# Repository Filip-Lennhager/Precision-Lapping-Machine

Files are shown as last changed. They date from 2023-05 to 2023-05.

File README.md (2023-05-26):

# Precision Lapping Machine

This project was created by:

+ Filip Lennhager, `filip@lennhager.se`
+ Filip Karlsson
+ Albin Magnusson
+ Ali Halbastian Abdulla
+ Anton Meuller
+ Christian Mallqui Castro
+ Toni Carillo

## Table of Contents

1. [Prototype](#prototype)
2. [Disc and Fixation](#disc-and-fixation)
3. [Gearbox](#gearbox)
4. [Control System](#control-system)
    + [PCB](#pcb)
        + [Electrical Schematic](#electrical-schematic)
        + [Physical Schematic](#electrical-schematic)
    + [Code](#code)

## Prototype

CAD model of the prototype:

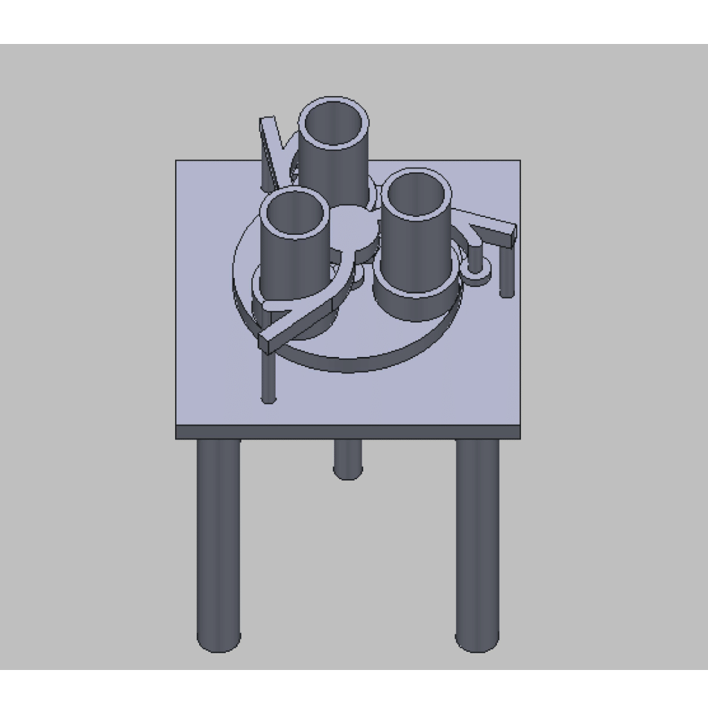
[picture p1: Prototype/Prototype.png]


## Disc and Fixation

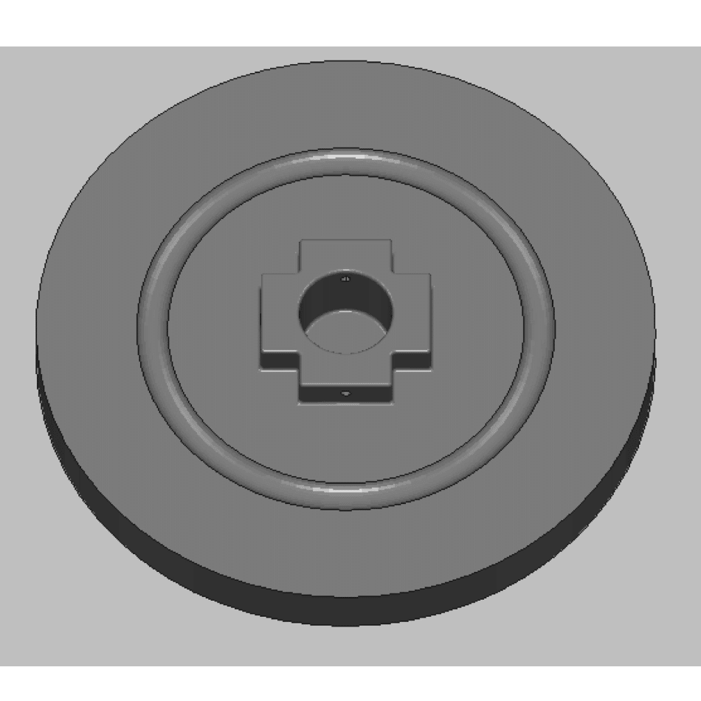
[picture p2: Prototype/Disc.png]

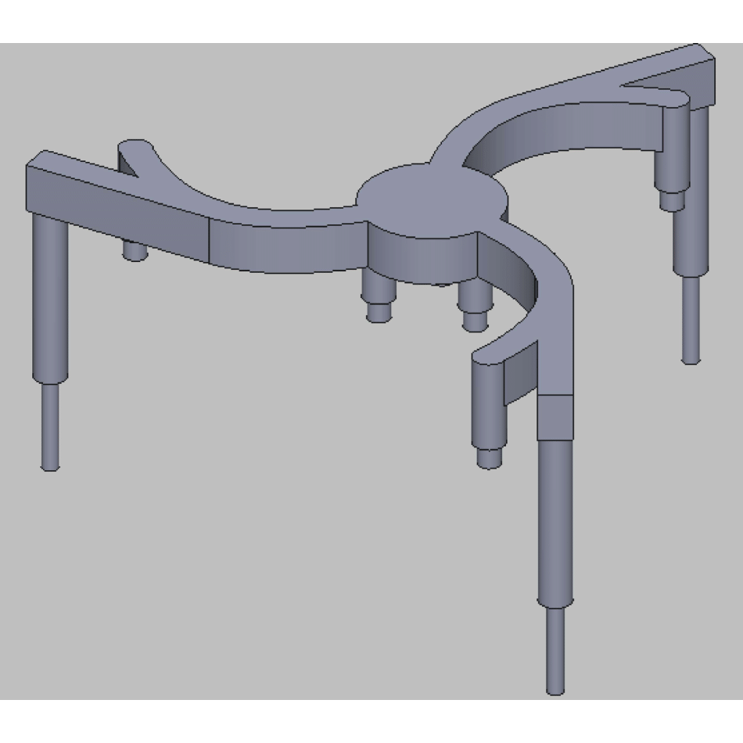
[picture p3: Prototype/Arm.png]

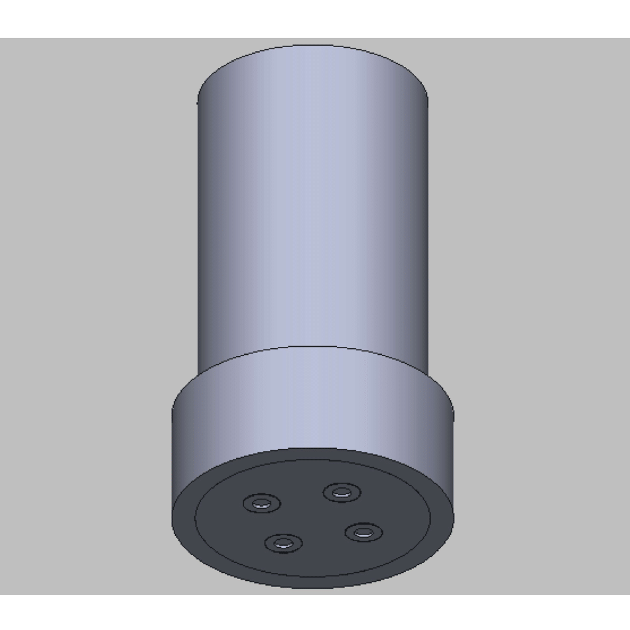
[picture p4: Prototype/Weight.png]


## Gearbox

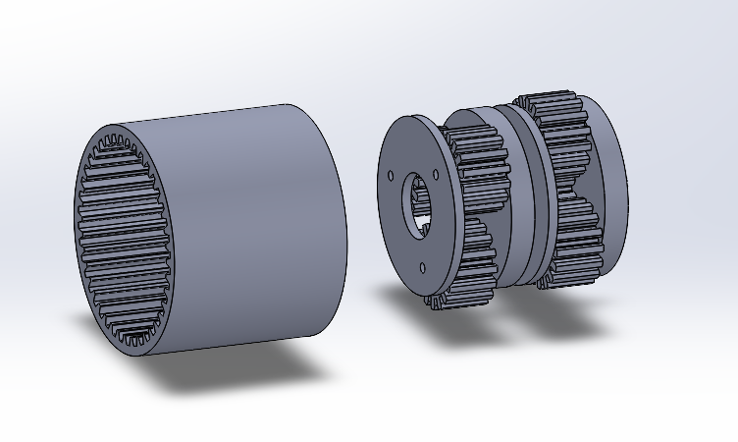
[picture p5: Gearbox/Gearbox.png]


## Control System

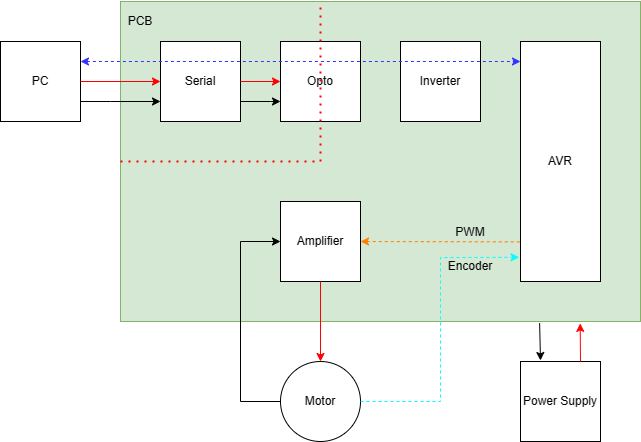
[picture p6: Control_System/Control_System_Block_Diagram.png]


### PCB

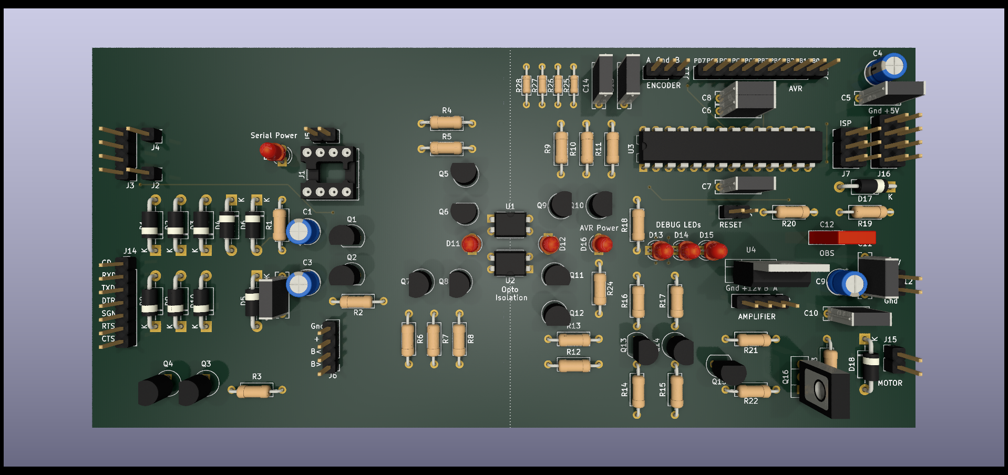
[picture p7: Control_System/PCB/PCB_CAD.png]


#### Electrical Schematic

An overview of the electrical schematic can be found in the file: [`Precision-Lapping-Machine-1.png`](Control_System/PCB/Electrical_Schematic/Precision-Lapping-Machine-1.png):

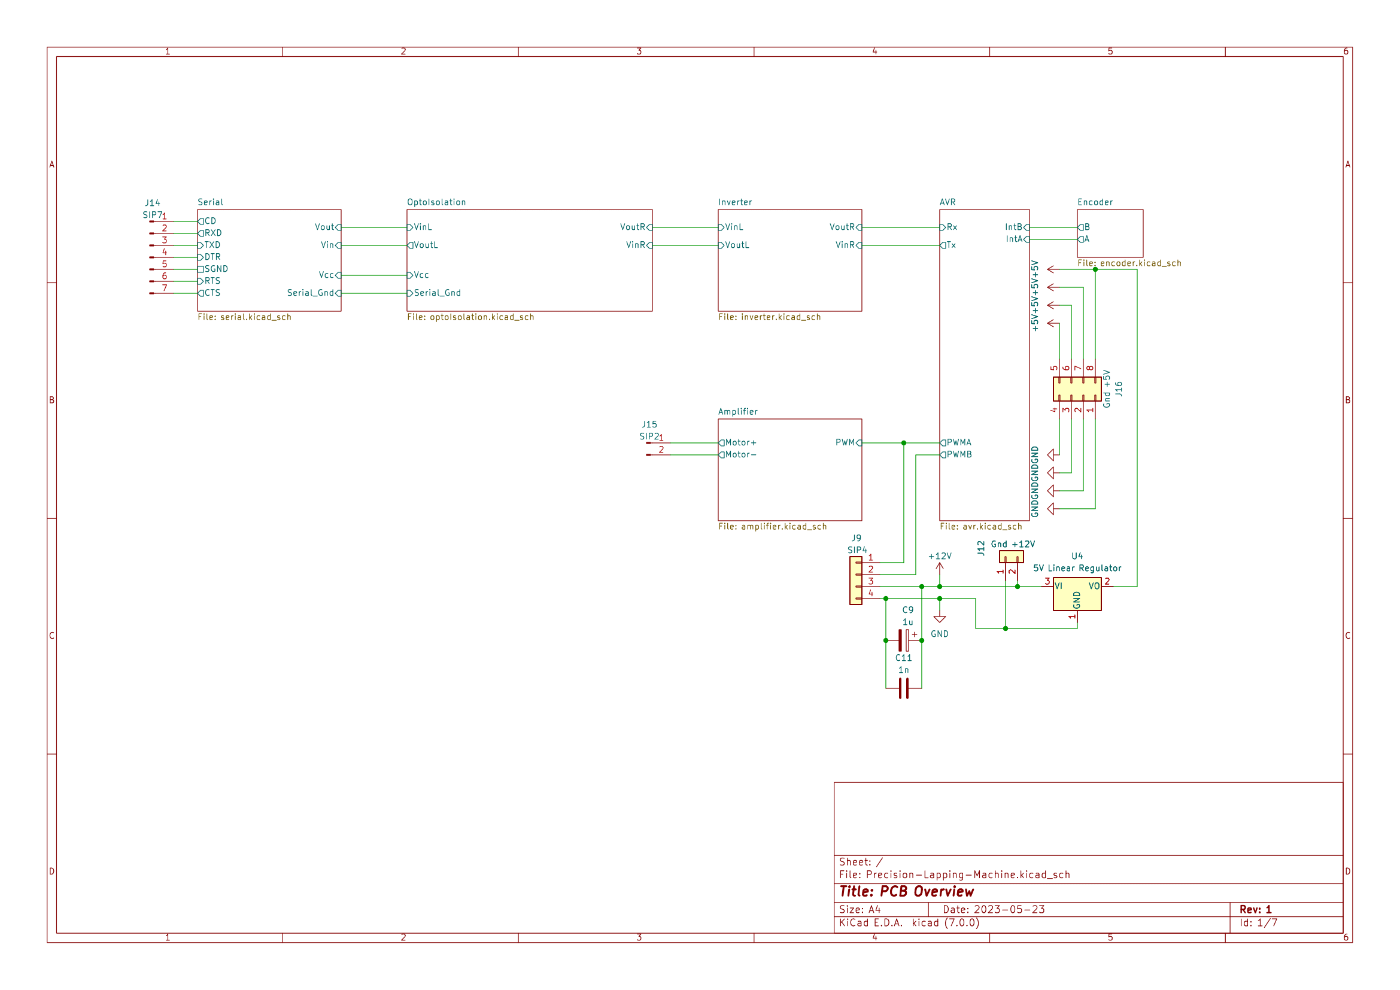
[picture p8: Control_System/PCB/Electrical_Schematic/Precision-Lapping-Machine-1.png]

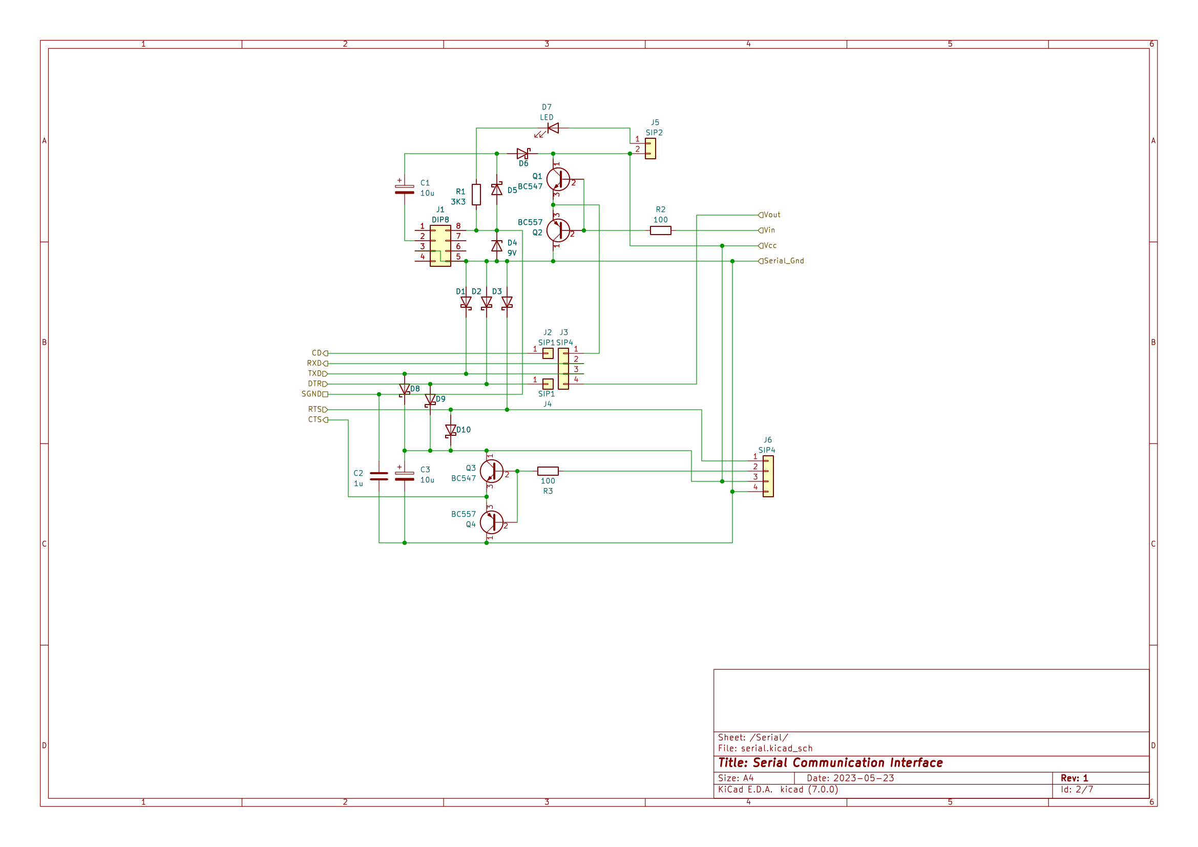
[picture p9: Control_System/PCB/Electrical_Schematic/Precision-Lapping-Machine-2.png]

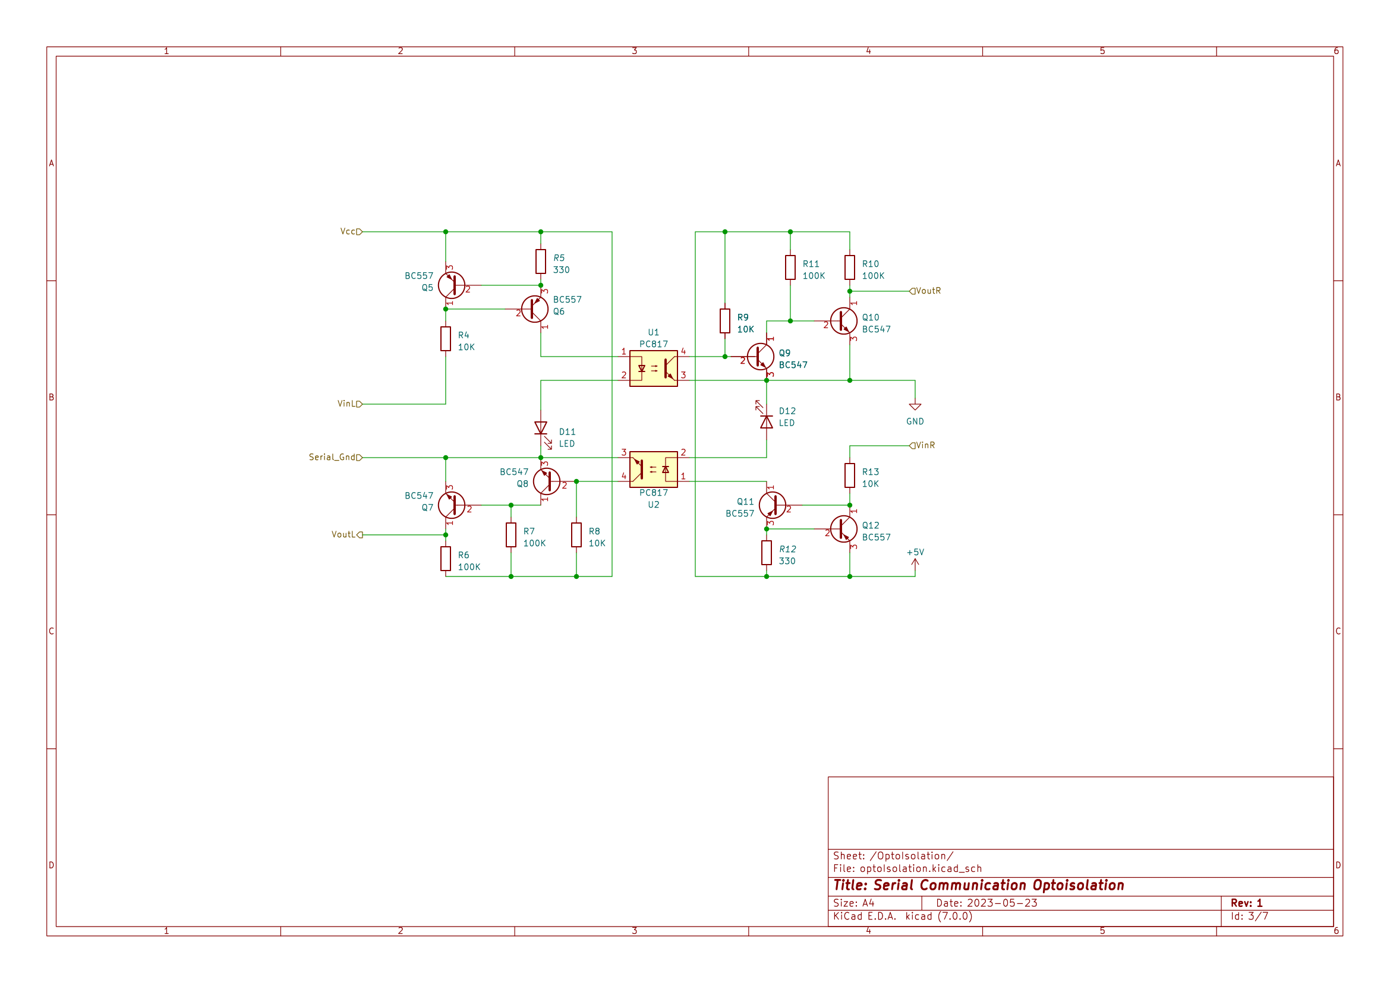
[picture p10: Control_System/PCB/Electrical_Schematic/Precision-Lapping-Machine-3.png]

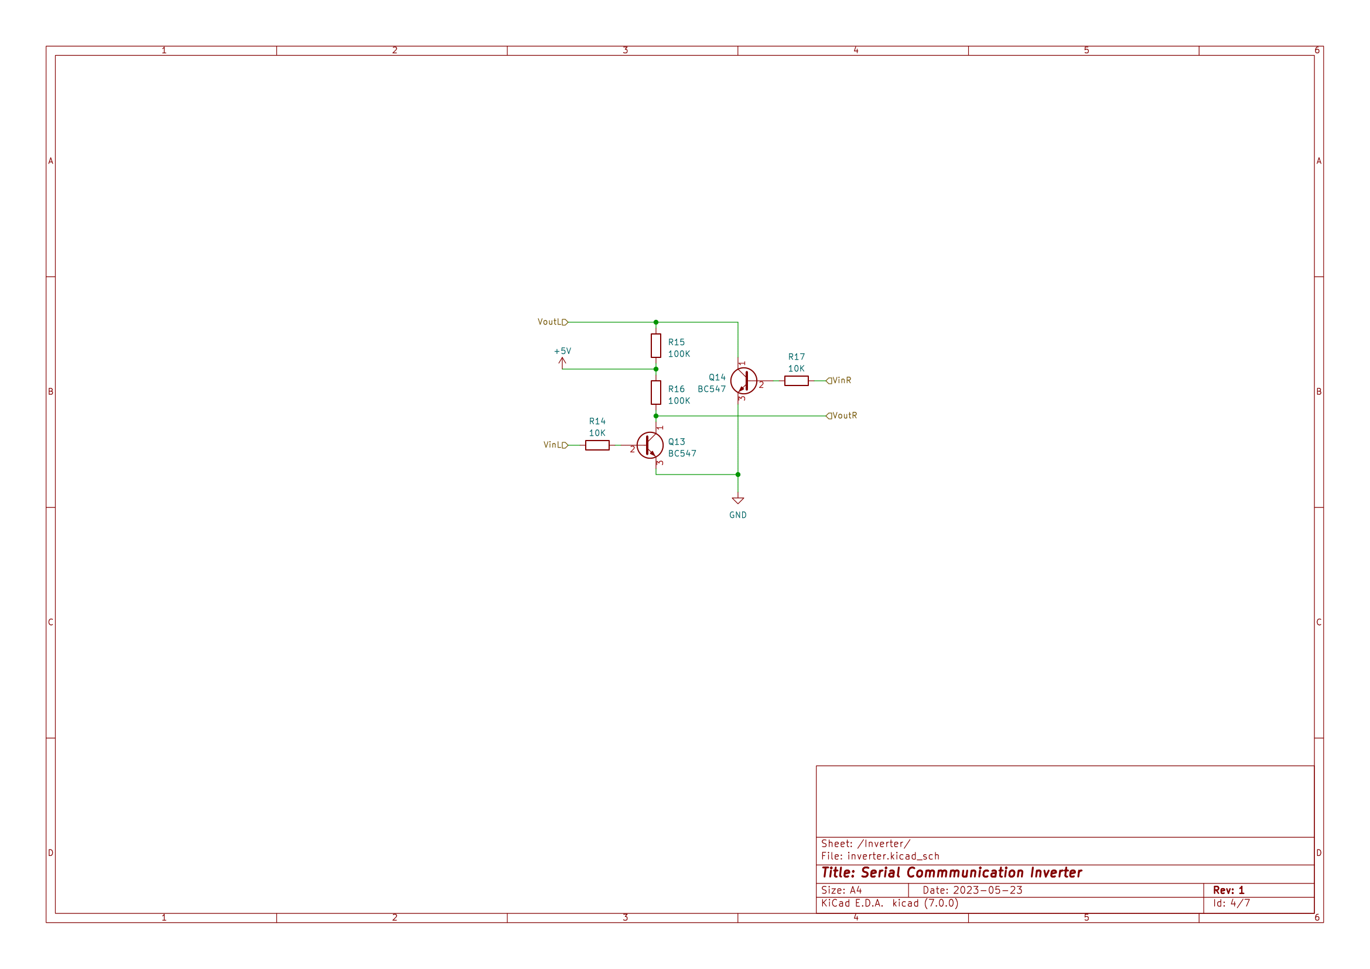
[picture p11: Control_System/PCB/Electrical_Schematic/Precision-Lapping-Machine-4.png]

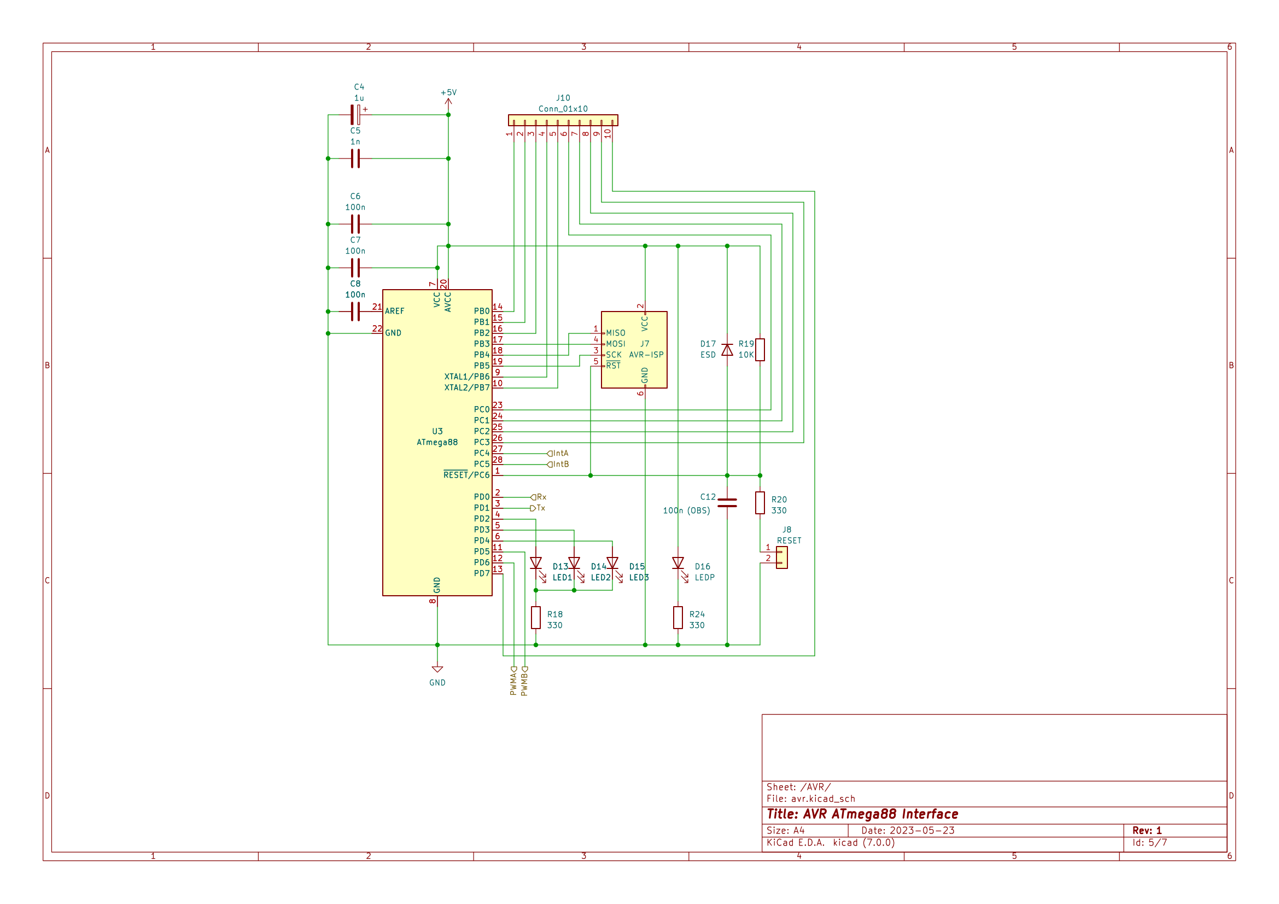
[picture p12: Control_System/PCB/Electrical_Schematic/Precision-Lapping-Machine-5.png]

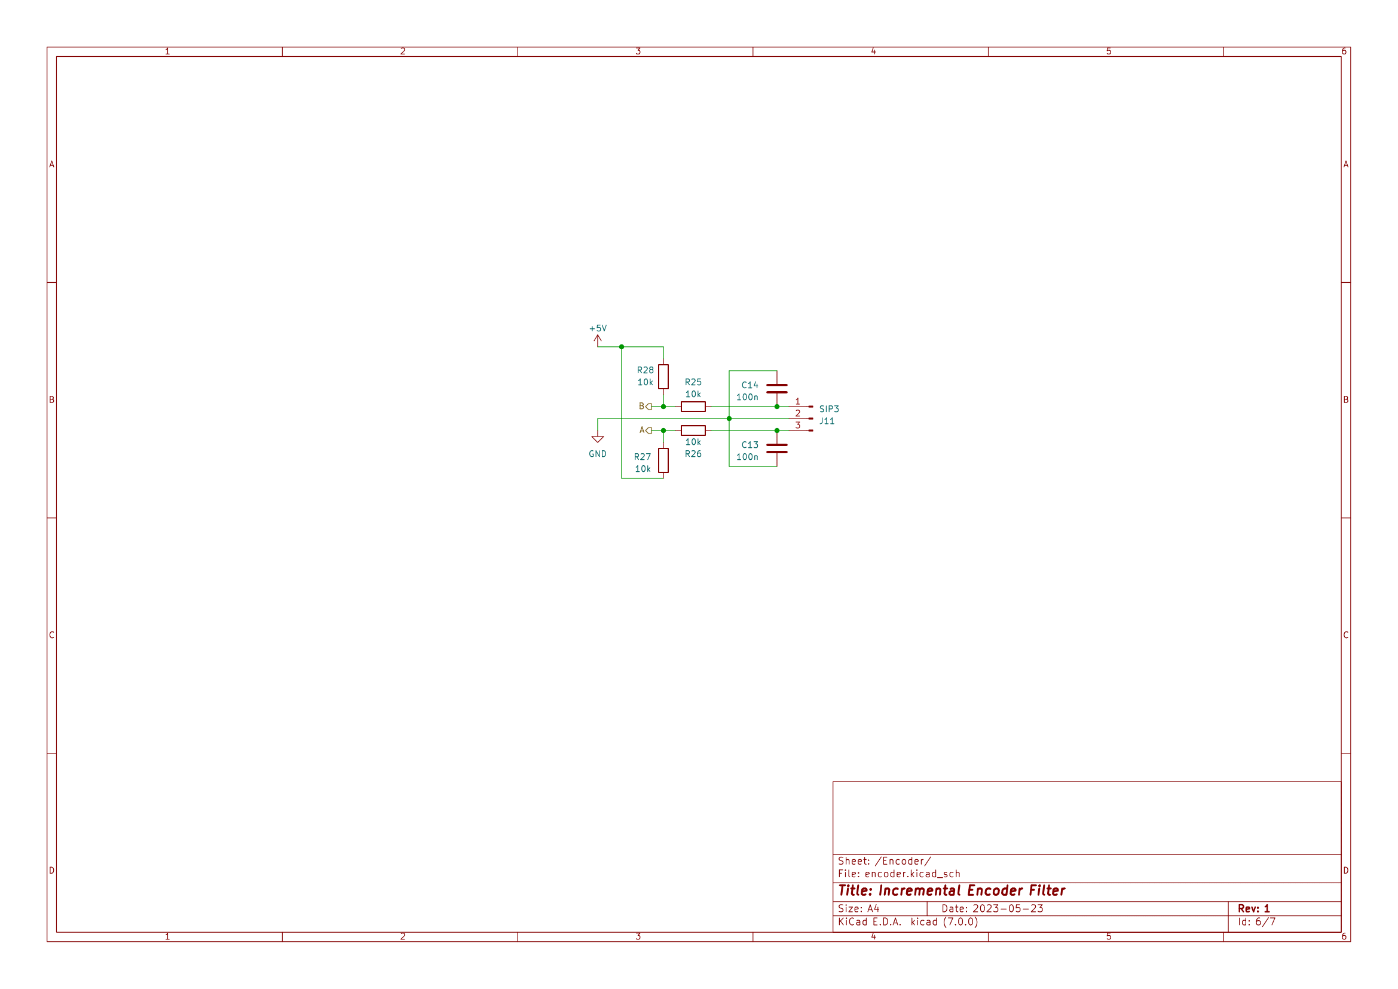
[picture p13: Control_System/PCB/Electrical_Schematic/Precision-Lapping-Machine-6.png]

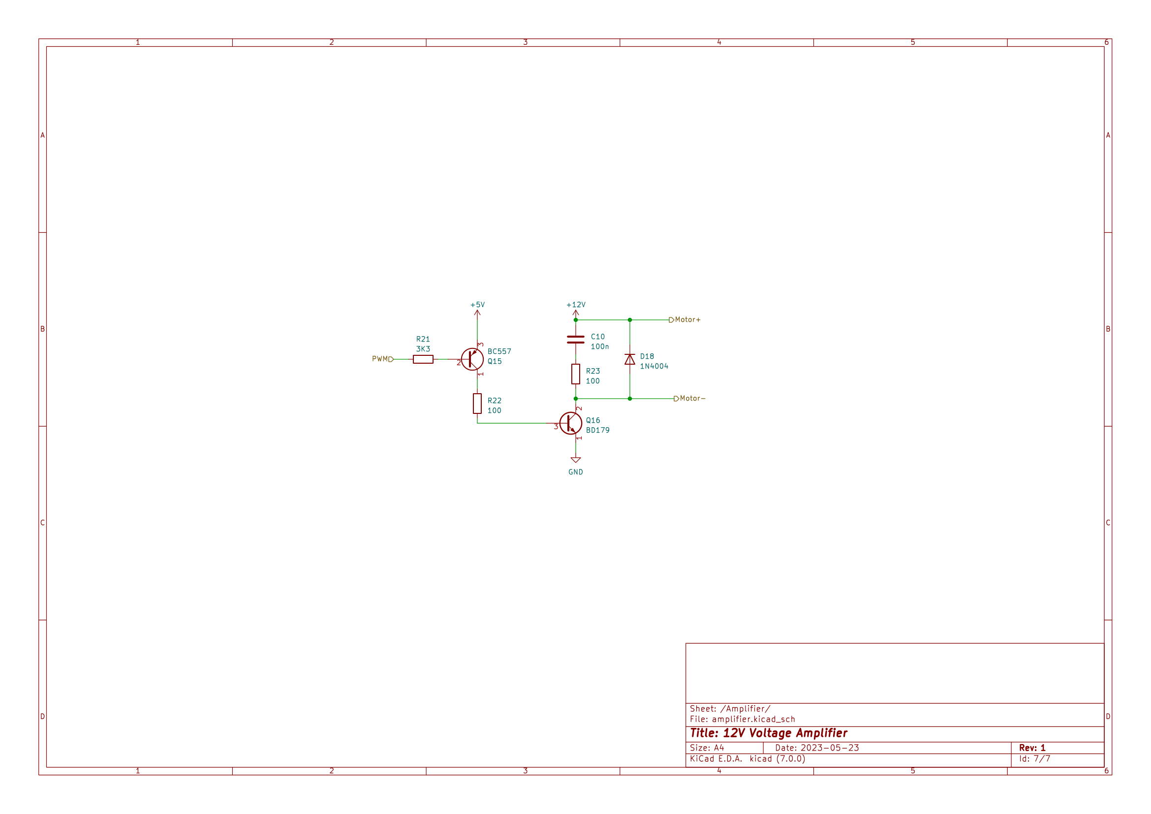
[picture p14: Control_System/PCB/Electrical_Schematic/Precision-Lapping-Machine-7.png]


#### Physical Schematic

Schematic of PCB with physical component placement:

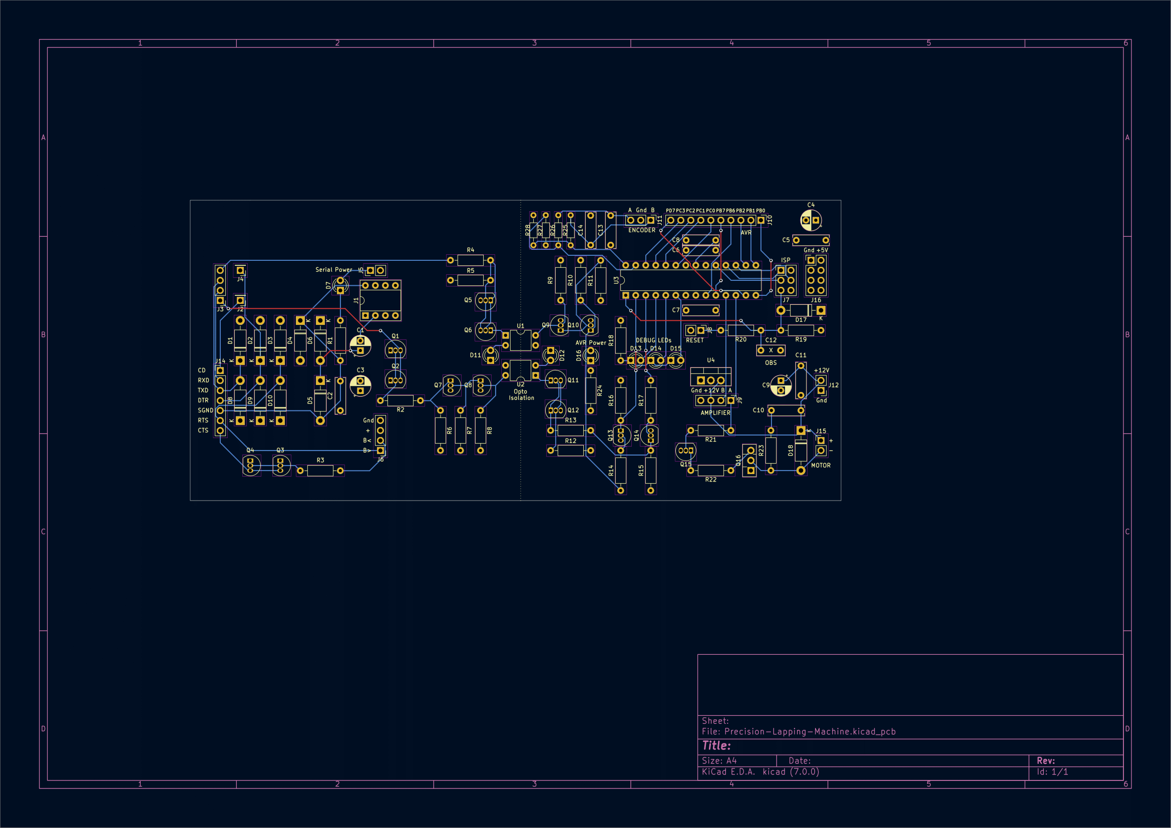
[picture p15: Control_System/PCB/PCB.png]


Gerber and drill files for pcb fabrication:

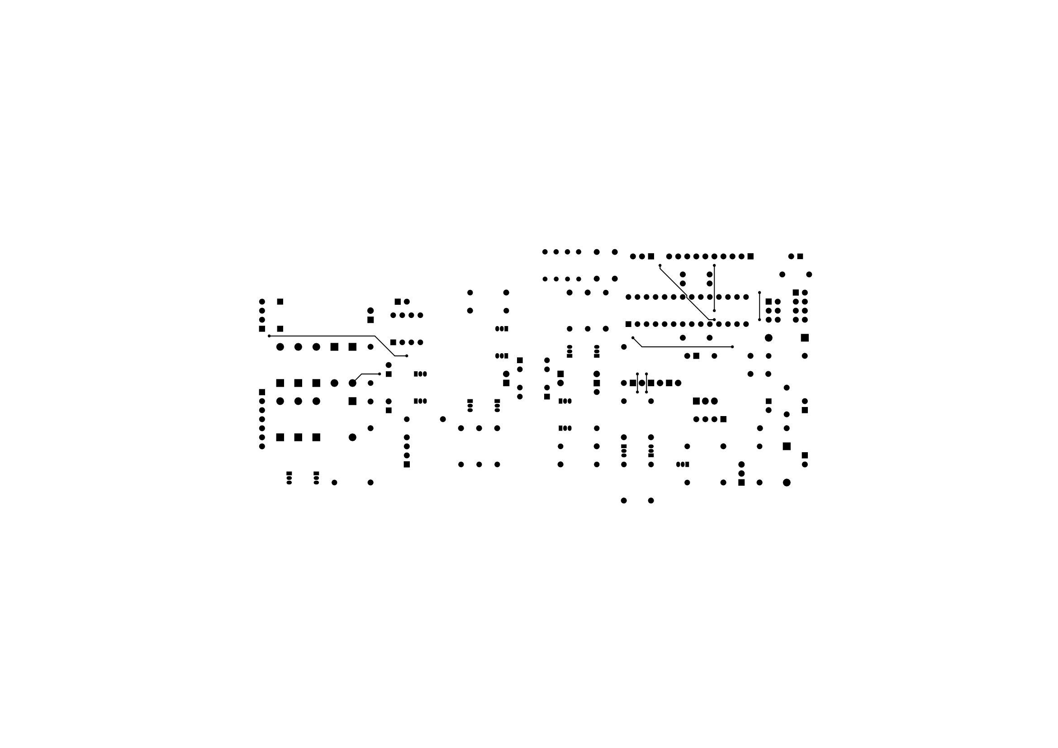
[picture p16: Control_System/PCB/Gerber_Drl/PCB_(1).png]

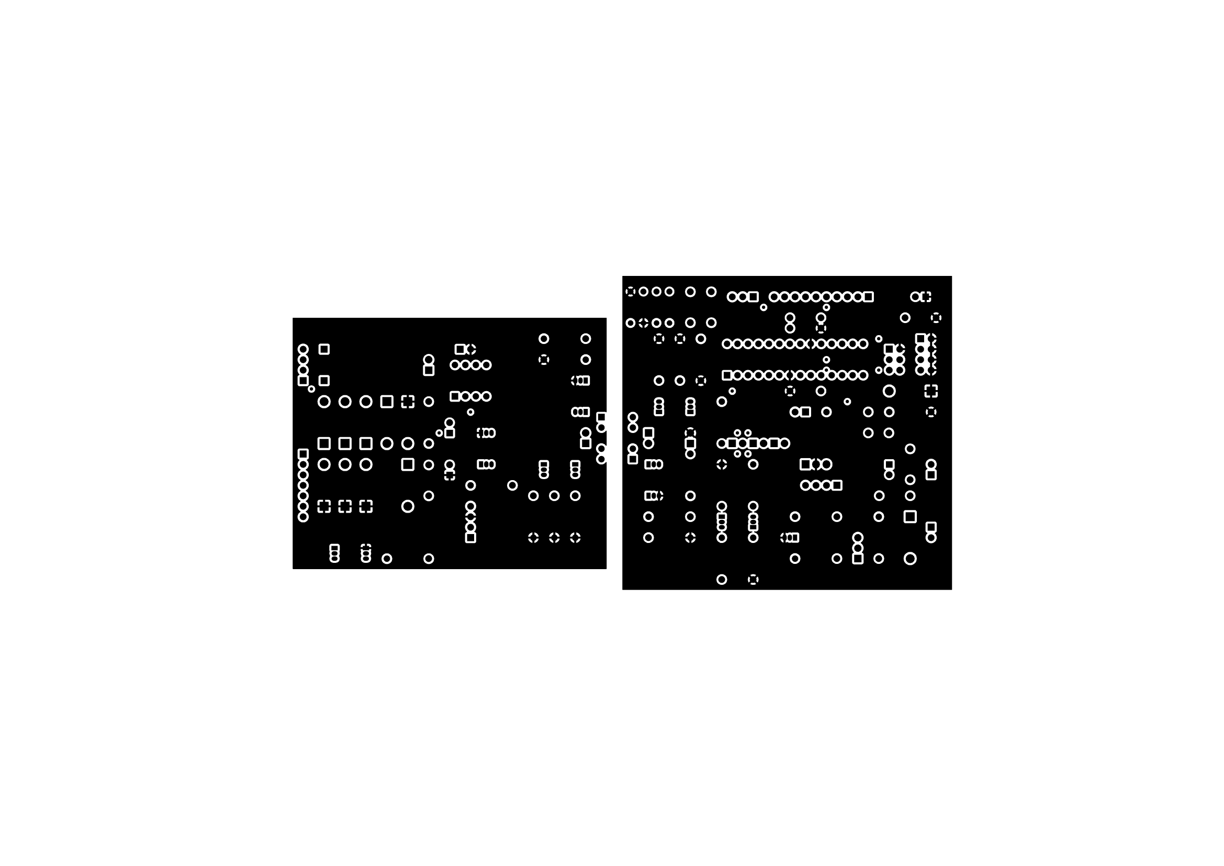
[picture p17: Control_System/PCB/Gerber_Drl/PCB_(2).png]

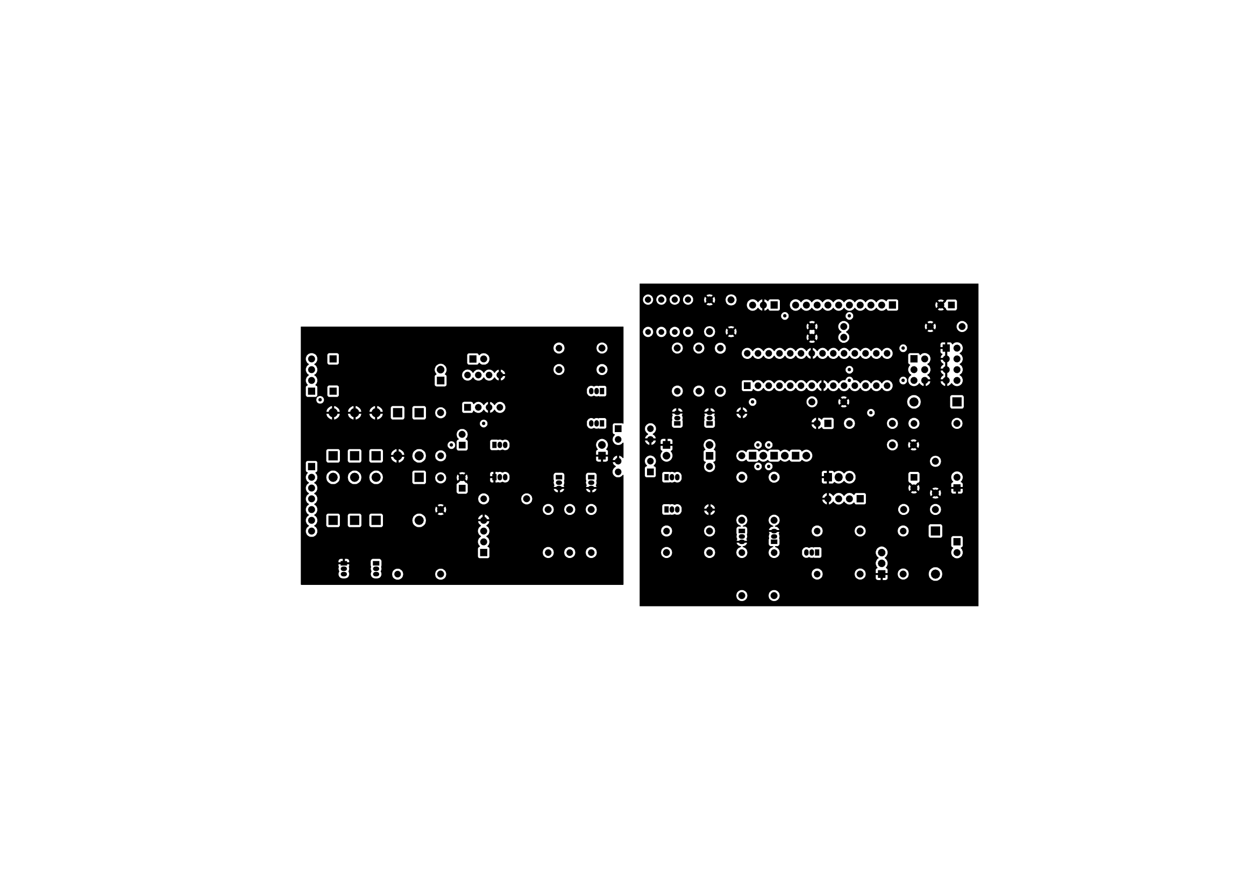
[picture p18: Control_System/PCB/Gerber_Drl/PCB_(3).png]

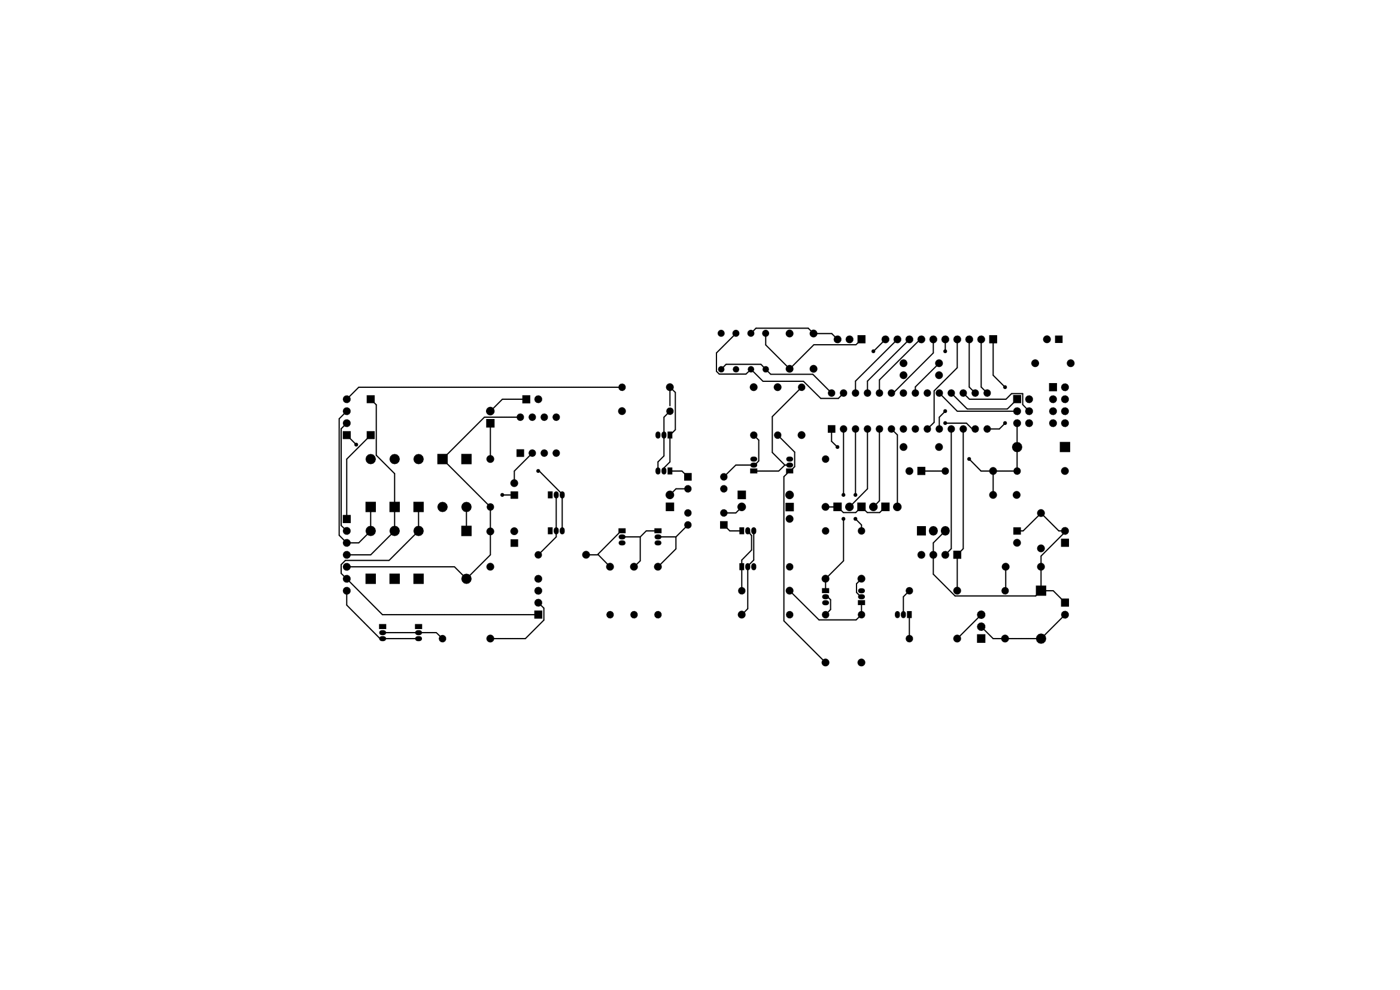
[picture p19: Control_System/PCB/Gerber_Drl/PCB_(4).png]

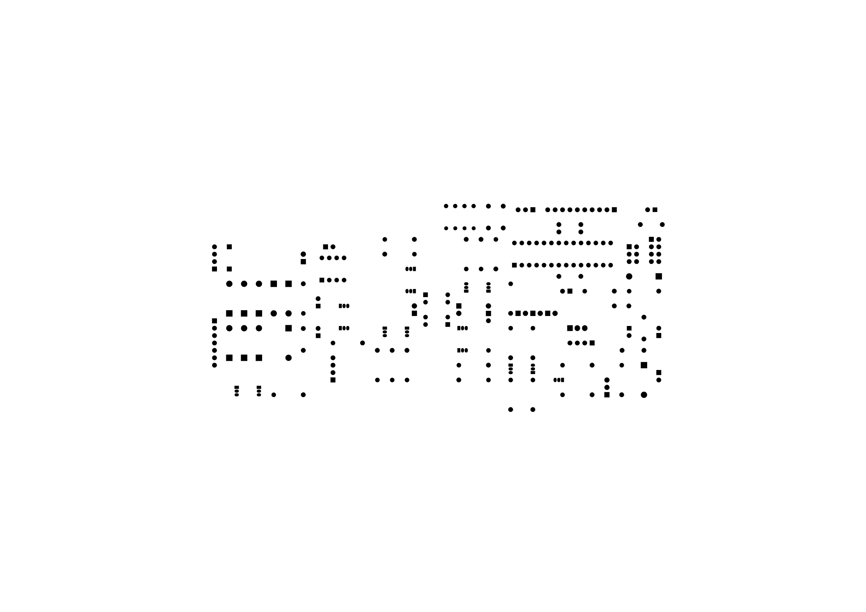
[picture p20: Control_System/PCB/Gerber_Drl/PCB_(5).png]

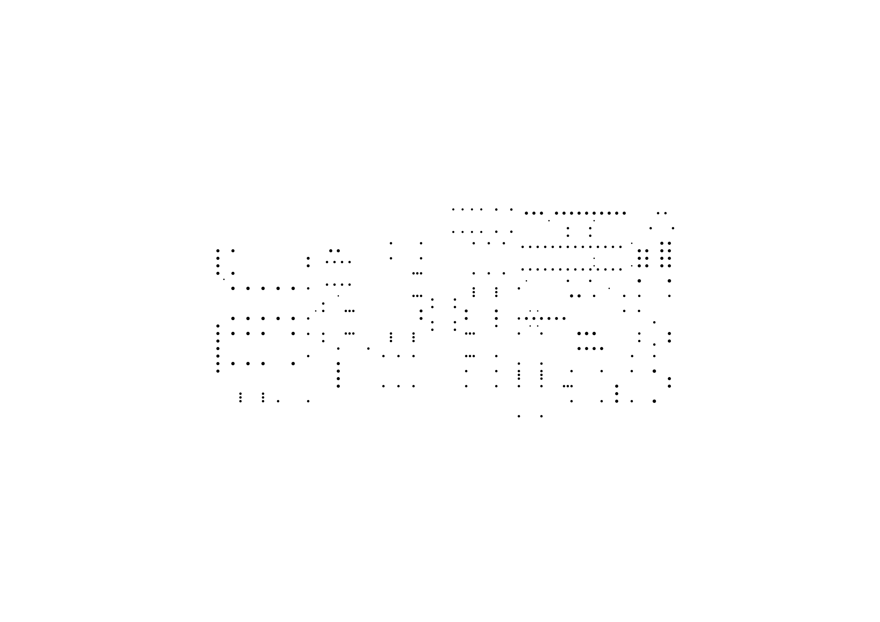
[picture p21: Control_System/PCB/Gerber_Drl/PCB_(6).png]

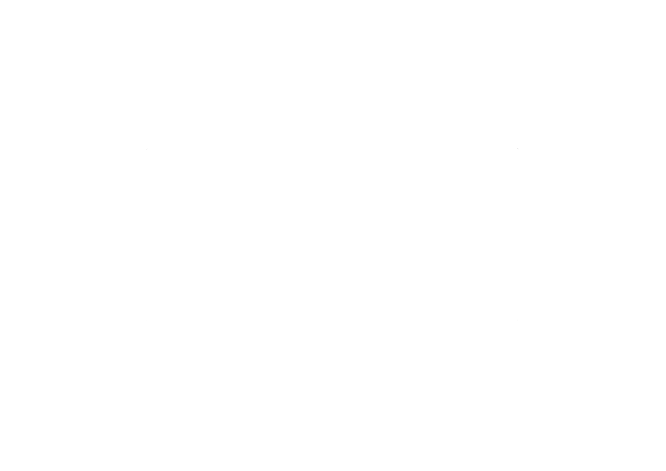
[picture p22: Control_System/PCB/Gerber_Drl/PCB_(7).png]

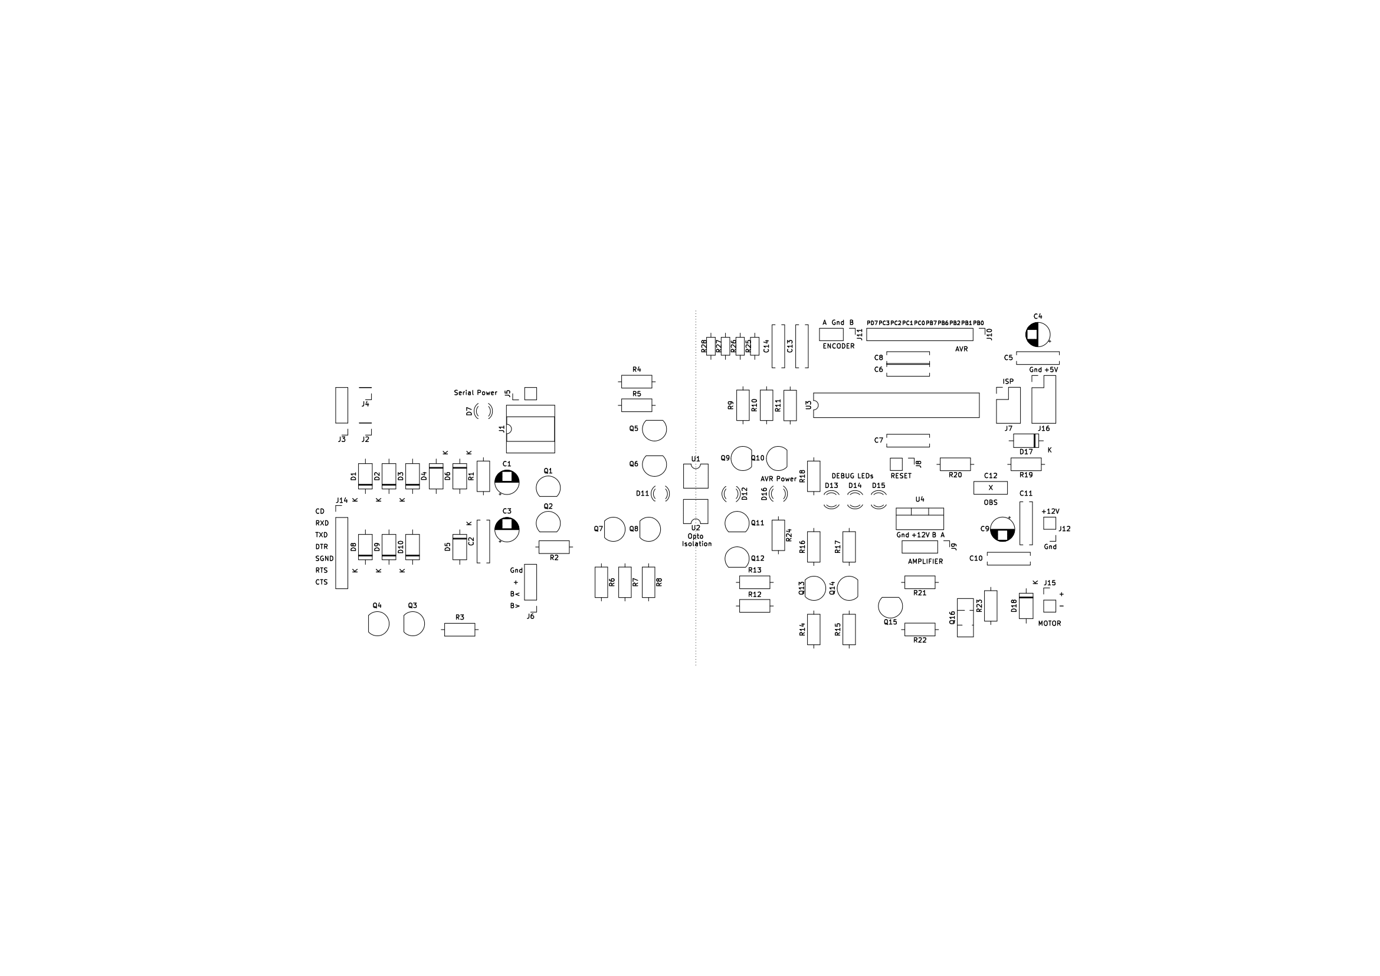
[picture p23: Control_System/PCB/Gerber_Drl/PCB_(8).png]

plot

### Code

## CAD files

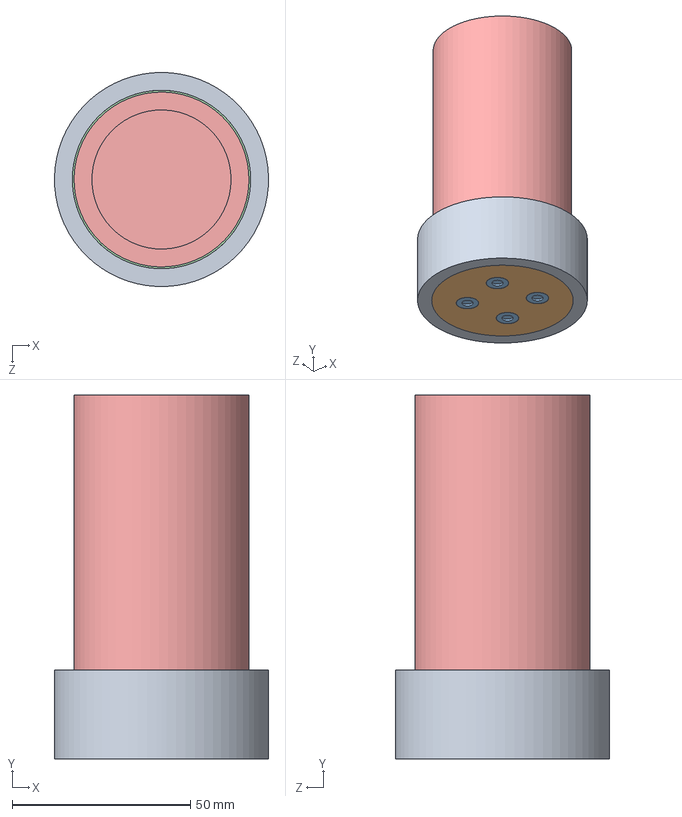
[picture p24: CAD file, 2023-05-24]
Prototype/Weight/smallPieceWeightAssem.SLDASM
60.0 x 102.0 x 60.0 mm
hardBorderPart
insertSmall
smallPiece x 4
yogaMat
sandCyl

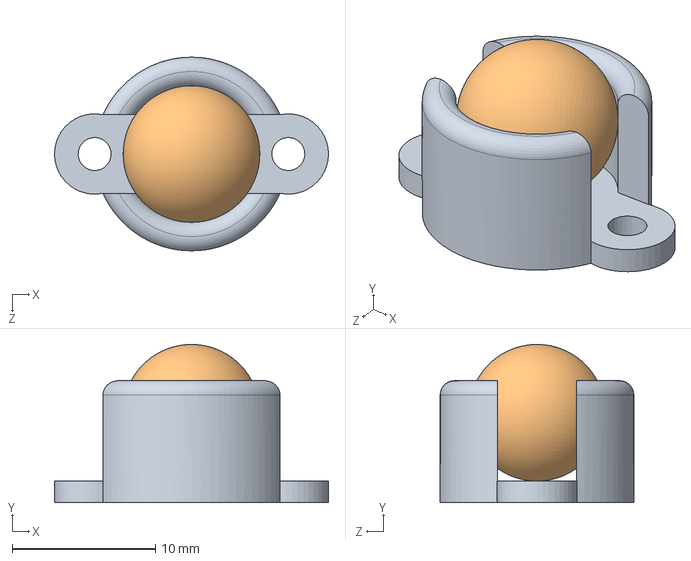
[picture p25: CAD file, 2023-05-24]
Prototype/Disk and Bearing Housing/comBallCaster.SLDASM
19.1 x 11.0 x 13.5 mm
ballcaster
Ball

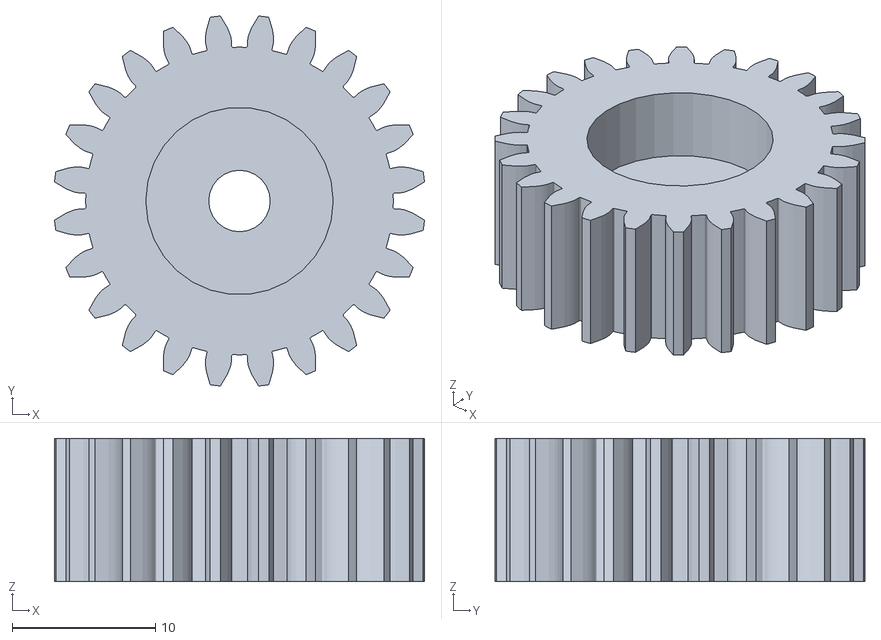
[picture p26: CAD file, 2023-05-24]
Gearbox/Body1_2.stl
25.9 x 25.9 x 10.0

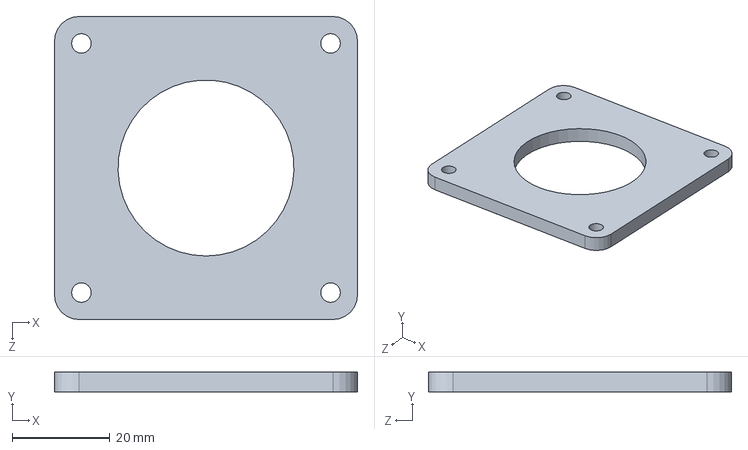
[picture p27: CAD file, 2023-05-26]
Prototype/Disk and Bearing Housing/Bearing_Housing_P2.SLDPRT
62.0 x 4.00 x 62.0 mm

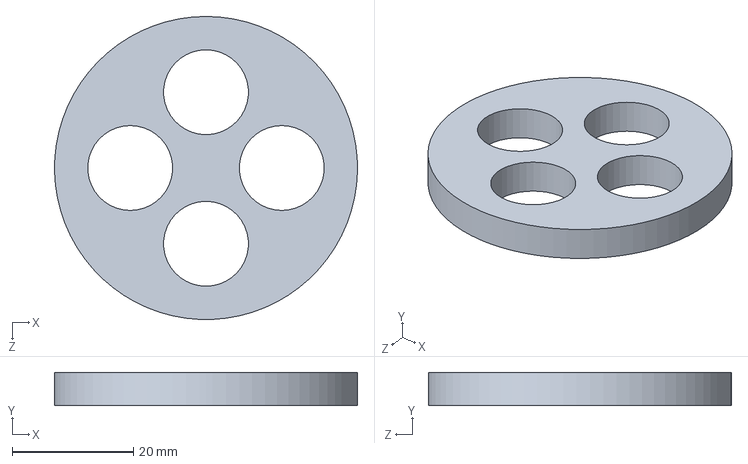
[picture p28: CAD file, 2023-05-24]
Prototype/Weight/insertBig.SLDPRT
50.0 x 5.50 x 50.0 mm

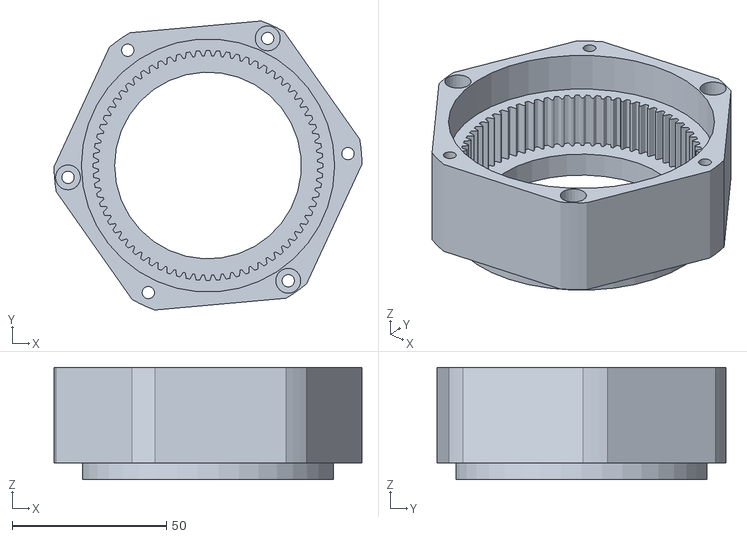
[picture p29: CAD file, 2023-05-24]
Gearbox/Body1_9.stl
100.0 x 93.8 x 36.5

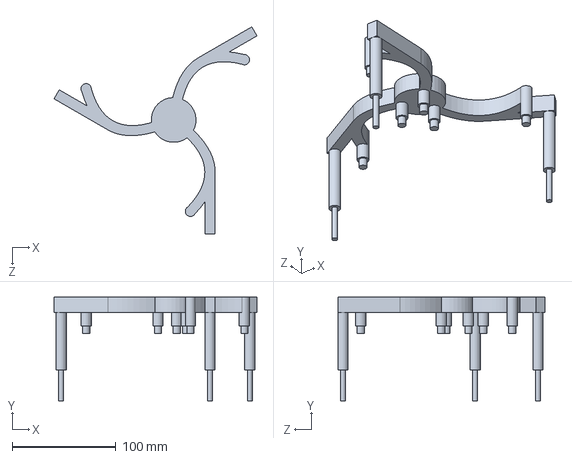
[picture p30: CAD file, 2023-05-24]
Prototype/Arm/wheelArm2.SLDPRT
195.5 x 100.0 x 199.6 mm

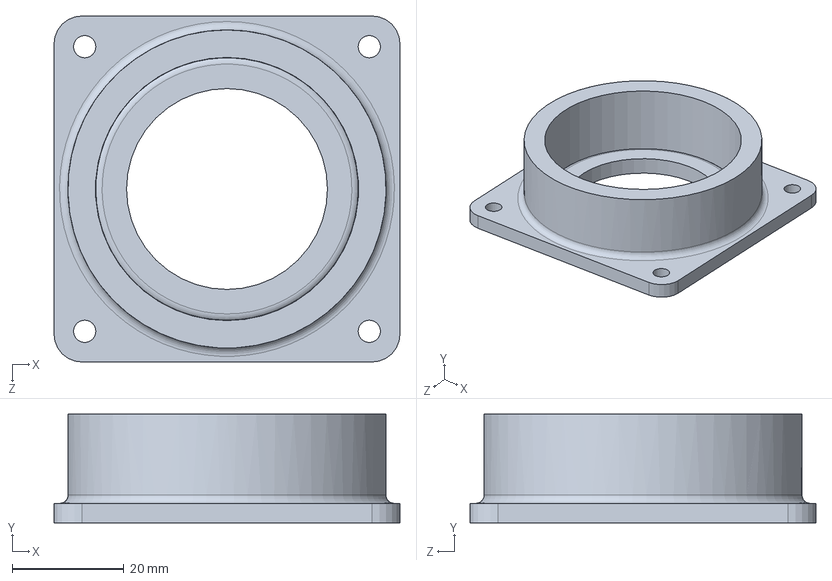
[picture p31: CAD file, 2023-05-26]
Prototype/Disk and Bearing Housing/Bearing_Housing.SLDPRT
62.0 x 19.5 x 62.0 mm

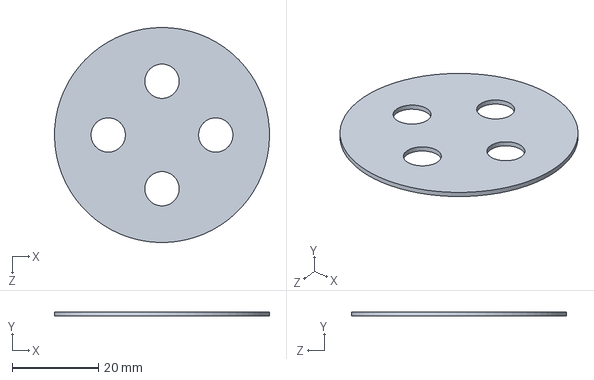
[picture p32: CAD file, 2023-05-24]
Prototype/Weight/insertSmall.SLDPRT
50.0 x 1.00 x 50.0 mm

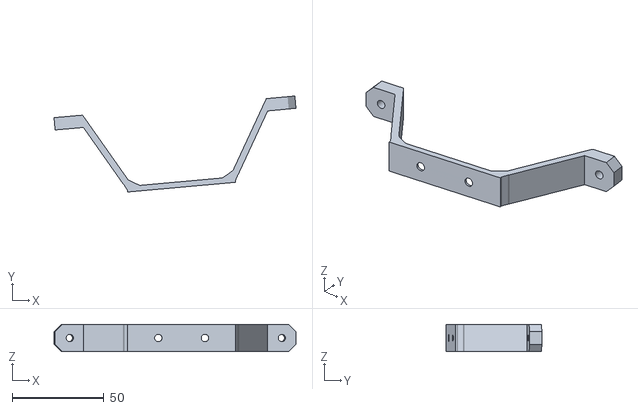
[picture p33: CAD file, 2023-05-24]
Gearbox/Body14.stl
132.1 x 52.4 x 15.0

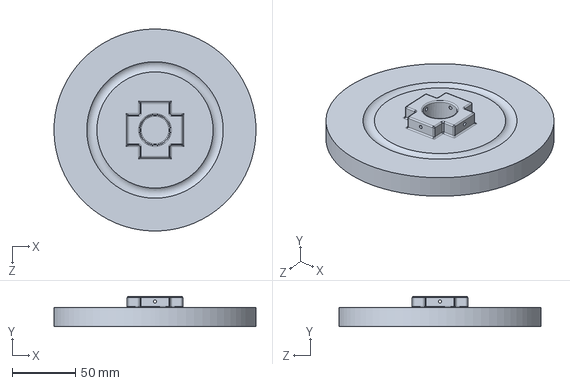
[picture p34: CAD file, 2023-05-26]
Prototype/Disk and Bearing Housing/SpinningPart_NewDesign.SLDPRT
160.0 x 24.0 x 160.0 mm

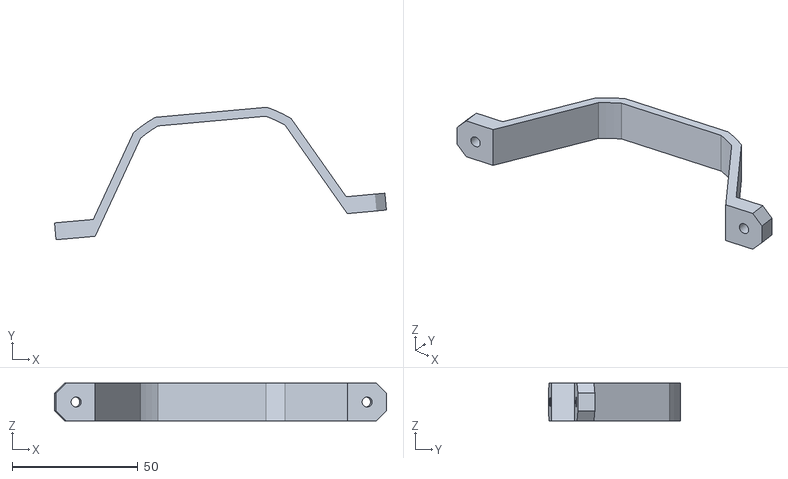
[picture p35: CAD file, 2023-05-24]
Gearbox/Body16.stl
132.0 x 52.7 x 15.0

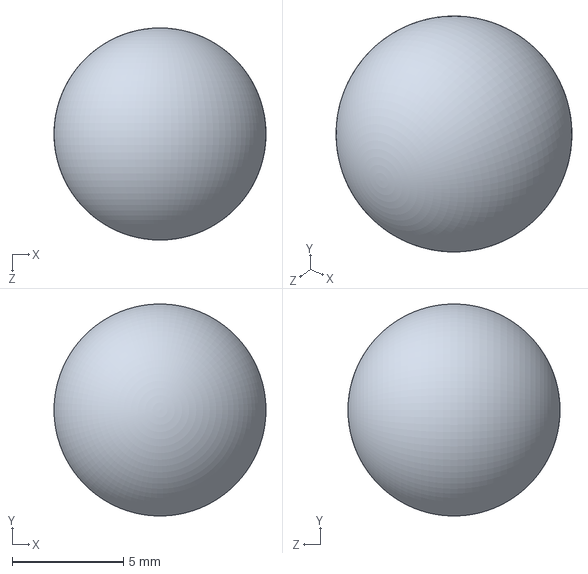
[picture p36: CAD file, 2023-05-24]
Prototype/Disk and Bearing Housing/Ball.SLDPRT
9.52 x 9.51 x 9.53 mm

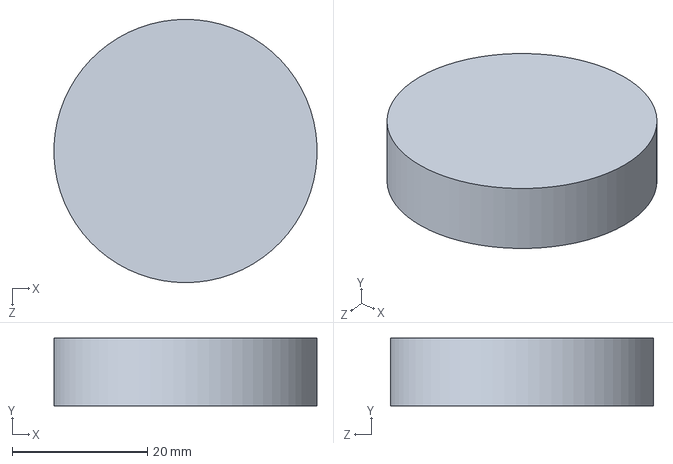
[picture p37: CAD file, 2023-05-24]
Prototype/Weight/sandCylIn.SLDPRT
39.0 x 10.0 x 39.0 mm

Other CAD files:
Prototype/Arm/wheelArm.SLDPRT
Gearbox/Body1_5.stl
Prototype/Disk and Bearing Housing/ballcaster.SLDPRT
Gearbox/Body1.stl
Gearbox/Body13 modified.STL
Gearbox/Body1_1.stl
Gearbox/Body1_3.stl
Gearbox/Body1_4.stl
Gearbox/Body1_6.stl
Gearbox/Body1_7.stl
Gearbox/Body1_8.stl
Prototype/Arm/wheelArm2.STL
Prototype/Disk and Bearing Housing/SpinningPart.SLDPRT
Prototype/Disk and Bearing Housing/SpinningPart_NewDesign.STL
Prototype/Disk and Bearing Housing/Stand.SLDPRT
Prototype/Disk and Bearing Housing/bearingArm.SLDPRT
Prototype/Weight/bigPiece.SLDPRT
Prototype/Weight/hardBorderPart.SLDPRT
Prototype/Weight/hardBorderPart.STL
Prototype/Weight/insertSmall.STL
Prototype/Weight/sandCyl.SLDPRT
Prototype/Weight/sandCyl.STL
Prototype/Weight/smallPiece.SLDPRT
Prototype/Weight/smallPiece.STL
Prototype/Weight/yogaMat.SLDPRT
Prototype/Weight/yogaMat.STL

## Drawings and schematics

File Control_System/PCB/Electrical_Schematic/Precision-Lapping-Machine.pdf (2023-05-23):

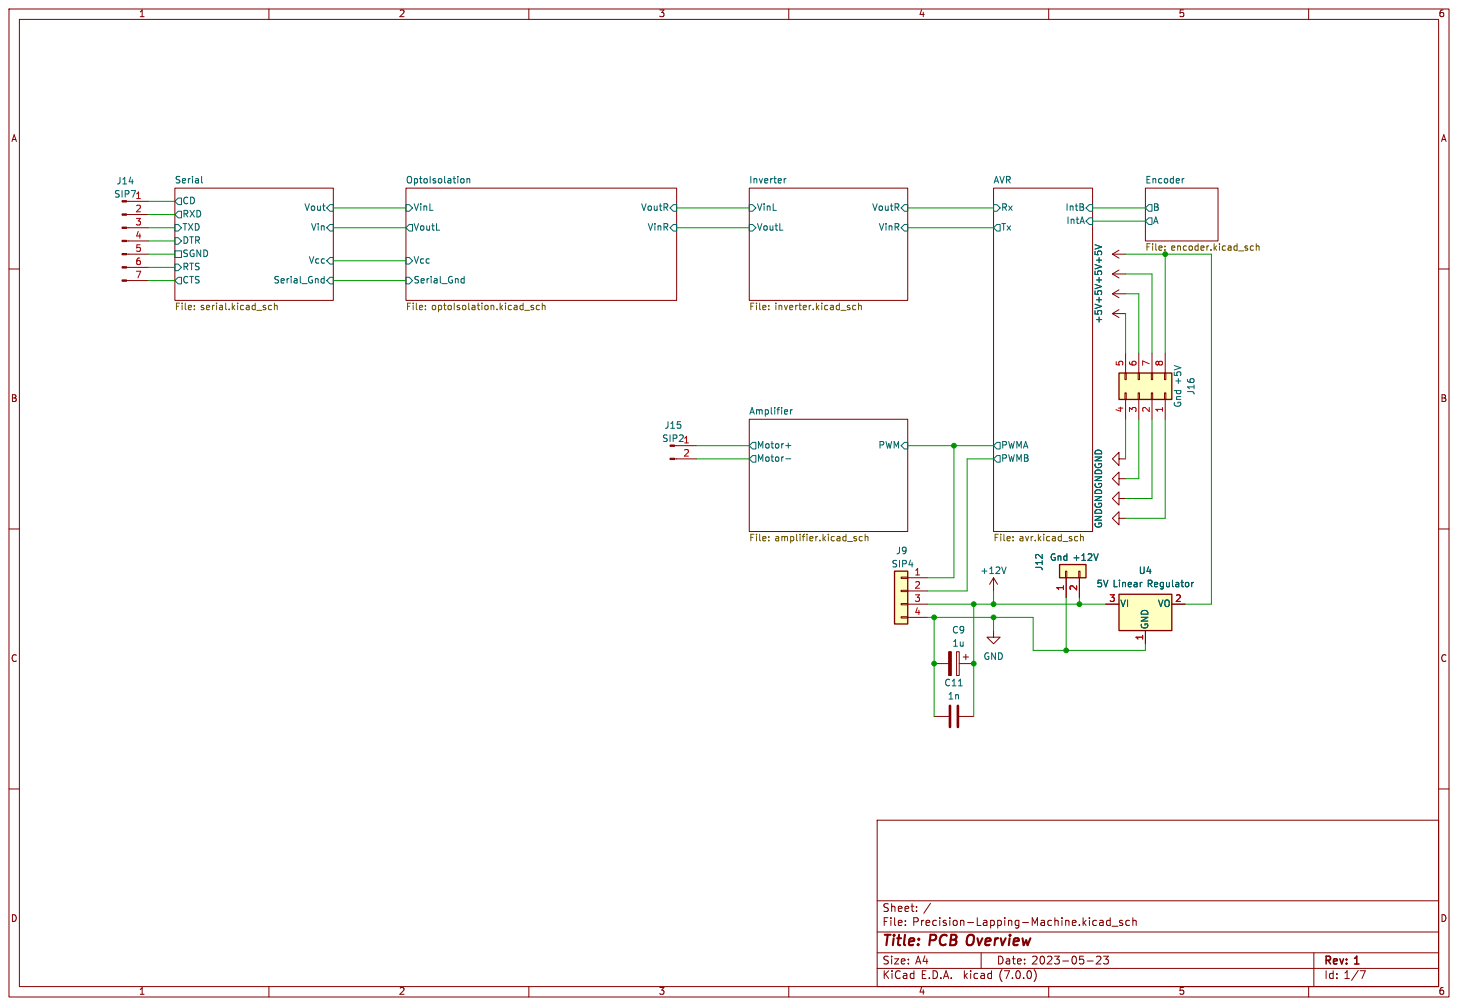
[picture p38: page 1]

Inverter File: inverter.kicad_sch Vout Vin Vcc DTR

Encoder File: encoder.kicad_sch Rx Tx

File: Precision-Lapping-Machine.kicad_sch Sheet: /
Id: 1/7 Title: PCB Overview

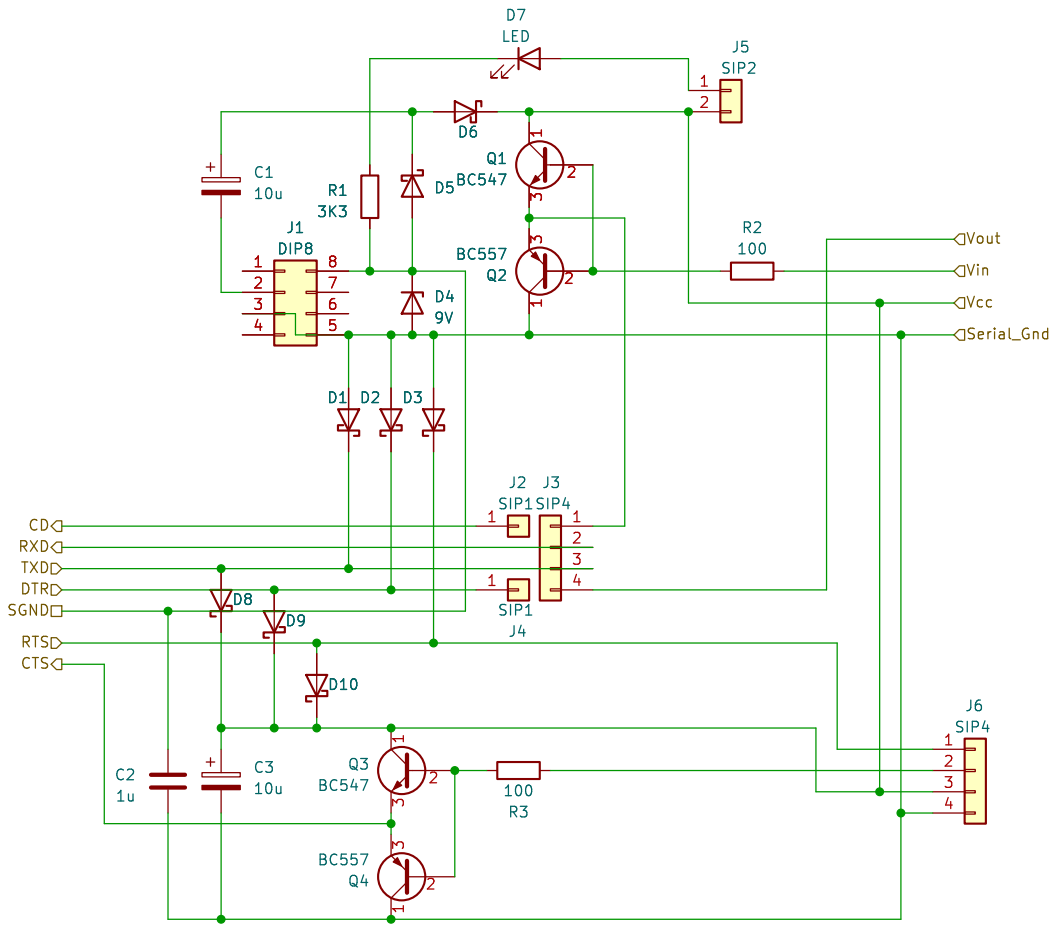
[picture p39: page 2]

J3 SIP4 1
File: serial.kicad_sch Sheet: /Serial/ 1234

Id: 2/7 Title: Serial Communication Interface

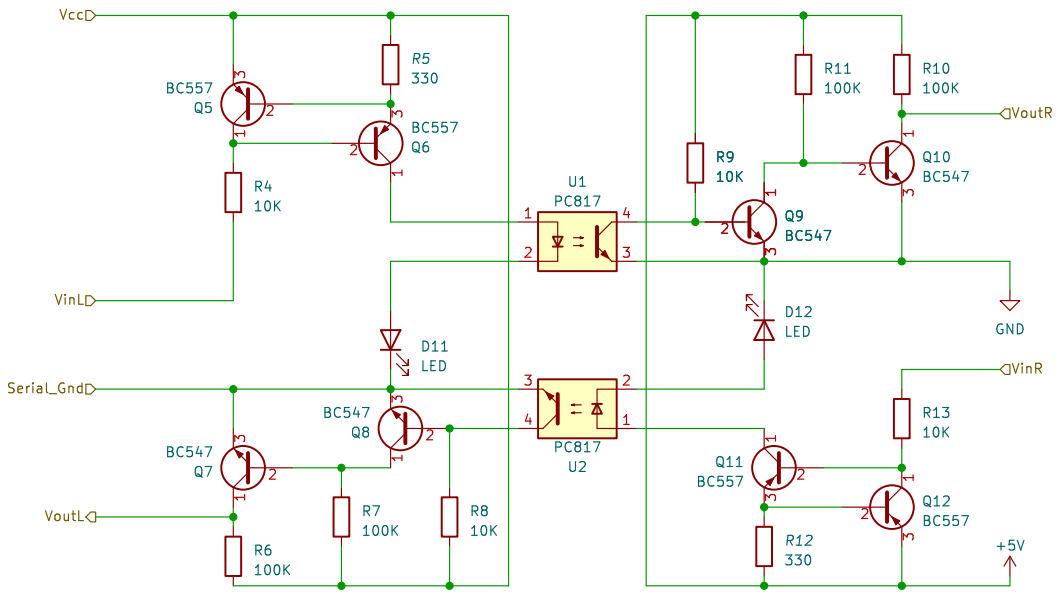
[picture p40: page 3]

File: optoIsolation.kicad_sch Sheet: /OptoIsolation/
Id: 3/7 Title: Serial Communication Optoisolation

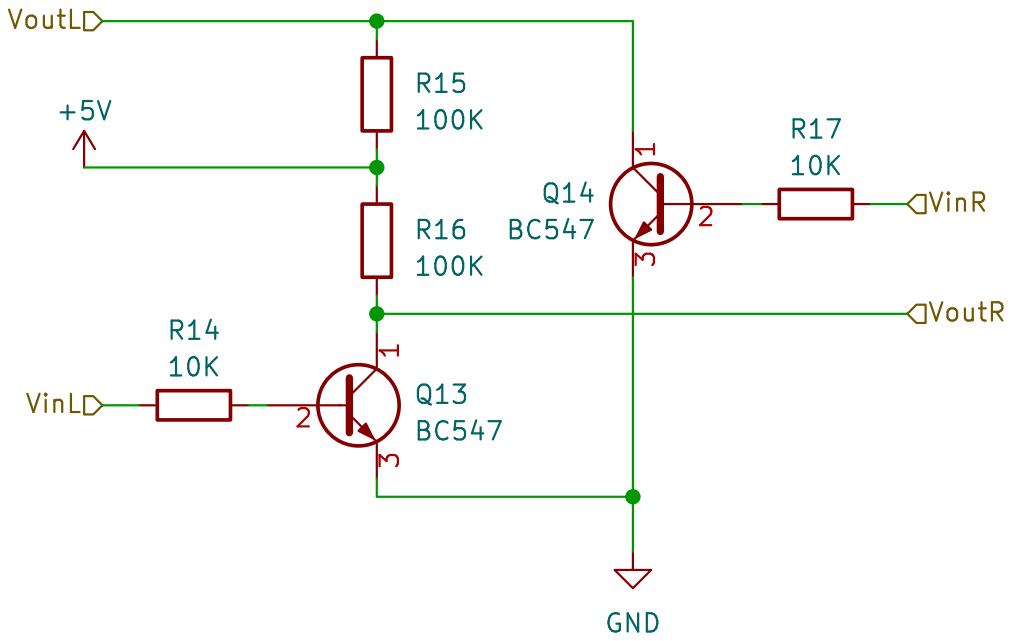
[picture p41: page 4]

Id: 4/7 Title: Serial Commmunication Inverter File: inverter.kicad_sch Sheet: /Inverter/

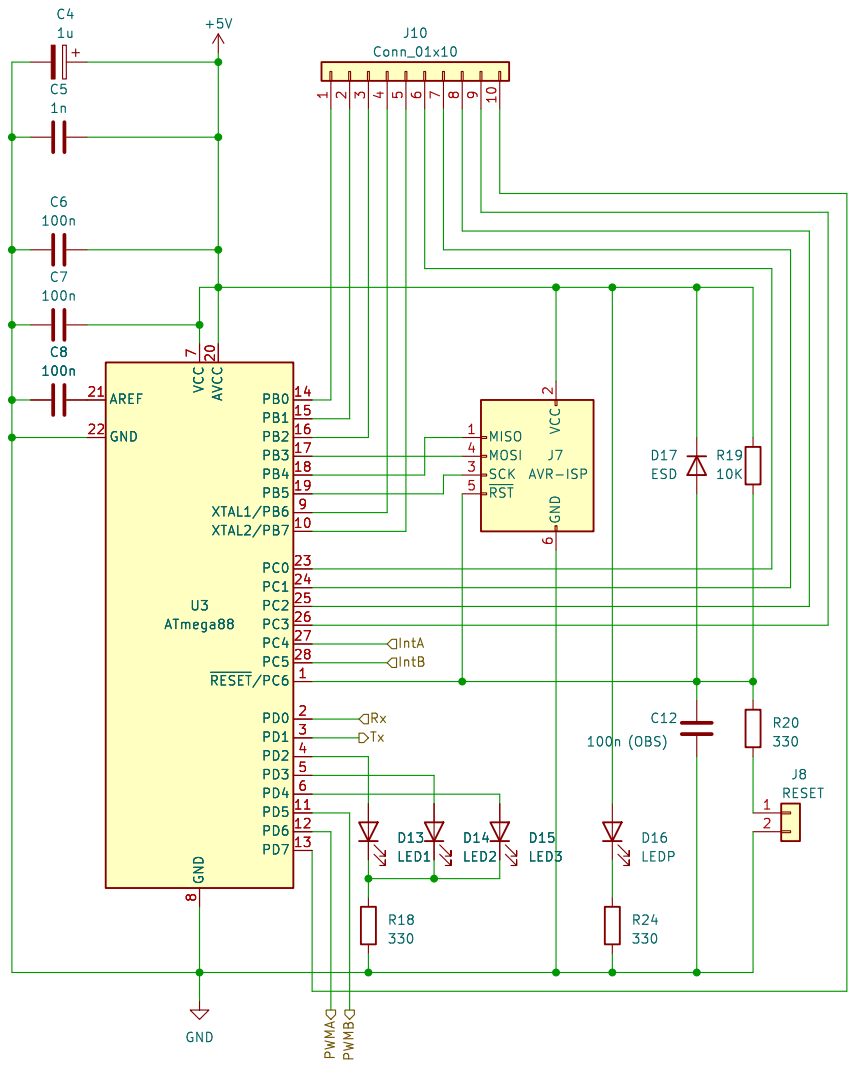
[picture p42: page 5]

File: avr.kicad_sch Sheet: /AVR/ D13

Id: 5/7 Title: AVR ATmega88 Interface

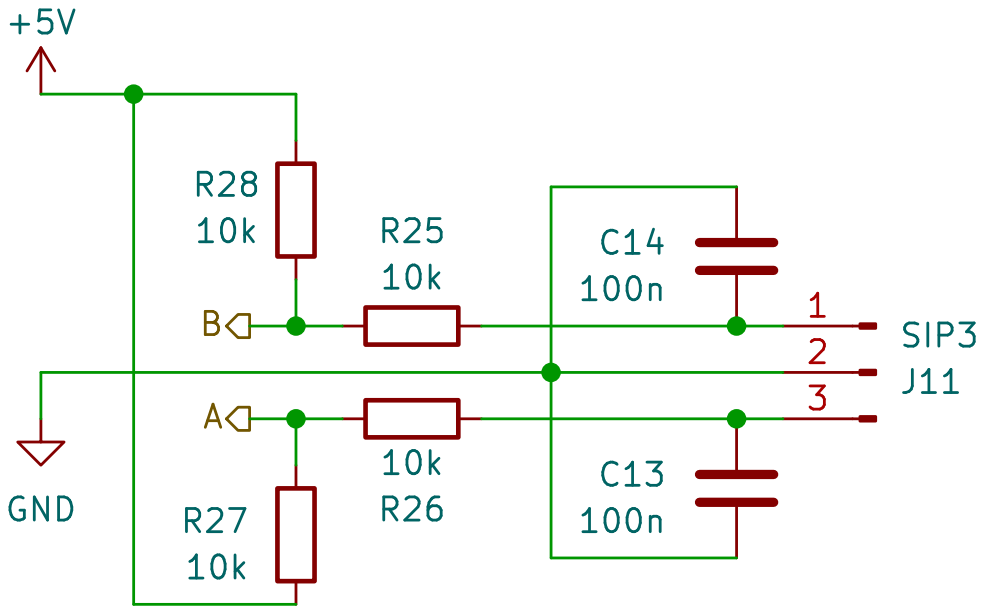
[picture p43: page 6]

Id: 6/7 Title: Incremental Encoder Filter File: encoder.kicad_sch Sheet: /Encoder/ R27

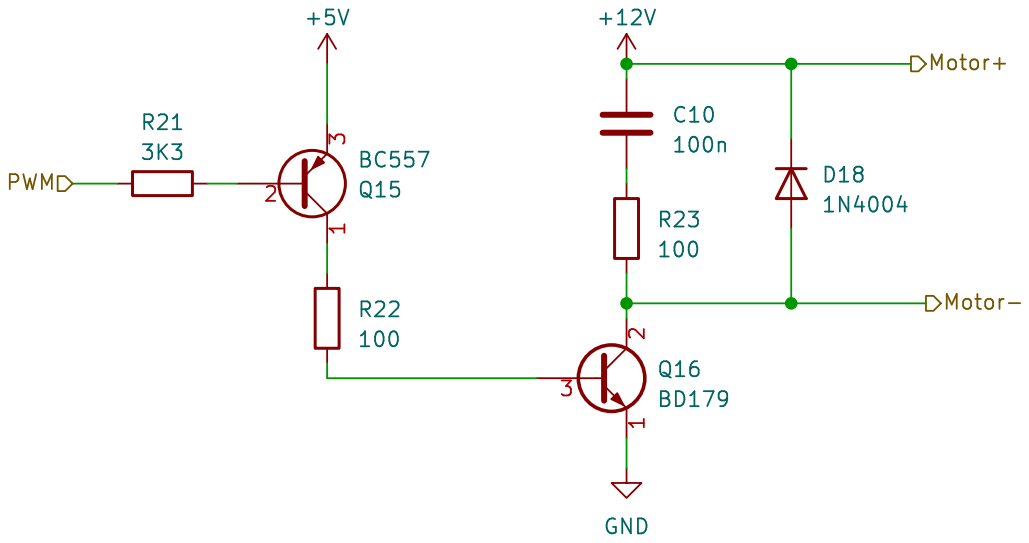
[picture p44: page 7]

Id: 7/7 Title: 12V Voltage Amplifier File: amplifier.kicad_sch Sheet: /Amplifier/

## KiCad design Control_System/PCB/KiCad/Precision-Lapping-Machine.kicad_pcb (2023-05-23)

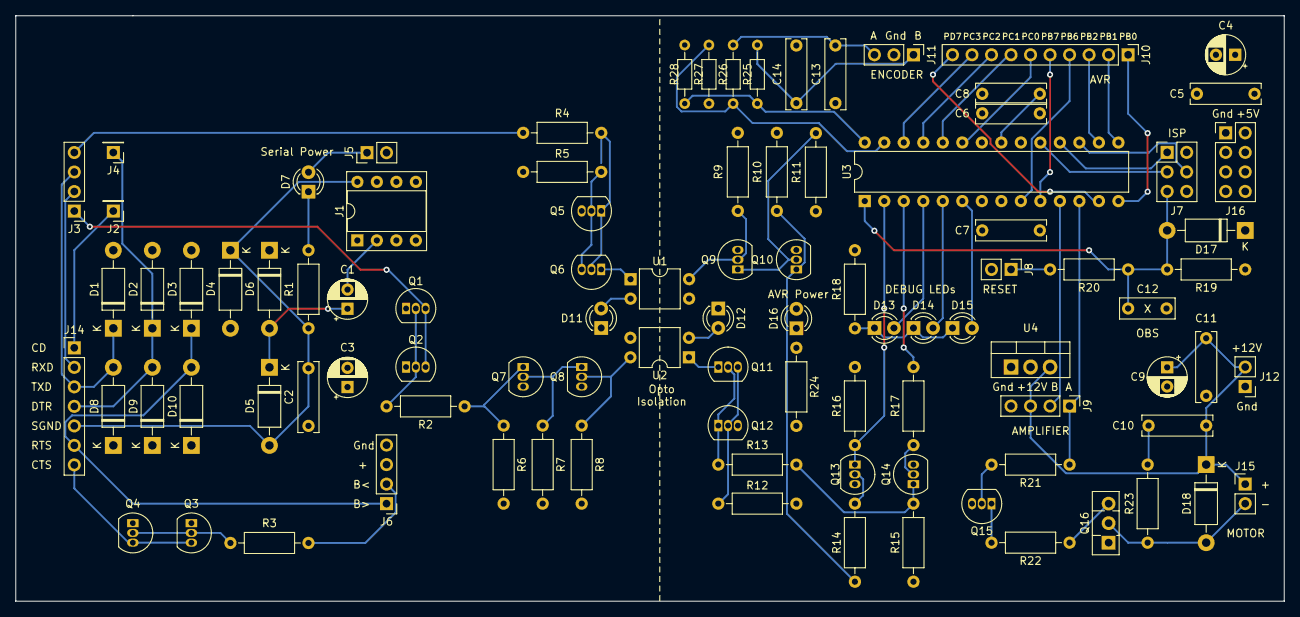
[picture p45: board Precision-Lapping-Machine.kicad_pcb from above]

Board: 4 copper layers, 165.1 x 76.2 mm, 95 parts (0 on the bottom side), 72 nets.

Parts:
C1, C3: 10u; CP_Radial_D5.0mm_P2.50mm
C2: 1u; C_Rect_L9.0mm_W2.5mm_P7.50mm_MKT
C4, C9: 1u; CP_Radial_D5.0mm_P2.50mm
C5, C11: 1n; C_Rect_L9.0mm_W2.5mm_P7.50mm_MKT
C6, C7, C8, C10, C13, C14: 100n; C_Rect_L9.0mm_W2.5mm_P7.50mm_MKT
C12: 100n (OBS); C_Rect_L7.0mm_W2.5mm_P5.00mm
D1, D2, D3, D5, D6, D8, D9, D10: D_DO-41_SOD81_P10.16mm_Horizontal
D4: 9V; D_DO-41_SOD81_P10.16mm_Horizontal
D7, D11, D12: LED; LED_D3.0mm
D13: LED1; LED_D3.0mm
D14: LED2; LED_D3.0mm
D15: LED3; LED_D3.0mm
D16: LEDP; LED_D3.0mm
D17: ESD; D_DO-41_SOD81_P10.16mm_Horizontal
D18: 1N4004; D_DO-41_SOD81_P10.16mm_Horizontal
J1: DIP8; DIP-8_W7.62mm_Socket
J2, J4: SIP1; PinHeader_1x01_P2.54mm_Vertical
J3, J6, J9: SIP4; PinHeader_1x04_P2.54mm_Vertical
J5, J15: SIP2; PinHeader_1x02_P2.54mm_Vertical
J7: AVR-ISP; PinHeader_2x03_P2.54mm_Vertical
J8: RESET; PinHeader_1x02_P2.54mm_Vertical
J10: Conn_01x10; PinHeader_1x10_P2.54mm_Vertical
J11: SIP3; PinHeader_1x03_P2.54mm_Vertical
J12: Gnd +12V; PinHeader_1x02_P2.54mm_Vertical
J14: SIP7; PinHeader_1x07_P2.54mm_Vertical
J16: Gnd +5V; PinHeader_2x04_P2.54mm_Vertical
Q1, Q3, Q7, Q8, Q9, Q10, Q13, Q14: BC547; TO-92_Inline
Q2, Q4, Q5, Q6, Q11, Q12, Q15: BC557; TO-92_Inline
Q16: BD179; TO-126-3_Vertical
R1, R21: 3K3; R_Axial_DIN0207_L6.3mm_D2.5mm_P10.16mm_Horizontal
R2, R3, R22, R23: 100; R_Axial_DIN0207_L6.3mm_D2.5mm_P10.16mm_Horizontal
R4, R8, R9, R13, R14, R17, R19: 10K; R_Axial_DIN0207_L6.3mm_D2.5mm_P10.16mm_Horizontal
R5, R12, R18, R20, R24: 330; R_Axial_DIN0207_L6.3mm_D2.5mm_P10.16mm_Horizontal
R6, R7, R10, R11, R15, R16: 100K; R_Axial_DIN0207_L6.3mm_D2.5mm_P10.16mm_Horizontal
R25, R26, R27, R28: 10k; R_Axial_DIN0204_L3.6mm_D1.6mm_P7.62mm_Horizontal
U1, U2: PC817; DIP-4_W7.62mm
U3: ATmega88; DIP-28_W7.62mm
U4: L7805CV; TO-220-3_Vertical

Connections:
+5V: C4.1, C5.2, C6.2, C7.2, D16.2 (A), D17.1 (K), J7.2 (VCC), J16.5, J16.6, J16.7, J16.8, Q12.3 (E), Q15.3 (E), R9.1, R10.1, R11.1, R12.2, R15.1, R16.2, R19.1, R27.2, R28.1, U3.7 (VCC), U3.20 (AVCC), U4.2 (VO)
+12V: C9.1, C10.1, C11.2, D18.1 (K), J9.3, J12.2, J15.1, U4.3 (VI)
/AVR/IntA: R26.2, R27.1, U3.27 (PC4)
/AVR/IntB: R25.2, R28.2, U3.28 (PC5)
/AVR/PWMA: J9.1, R21.1, U3.12 (PD6)
/AVR/PWMB: J9.2, U3.11 (PD5)
/AVR/Rx: Q13.1 (C), R16.1, U3.2 (PD0)
/AVR/Tx: R17.2, U3.3 (PD1)
/Amplifier/Motor-: D18.2 (A), J15.2, Q16.2 (C), R23.1
/Inverter/VinL: Q10.1 (C), R10.2, R14.1
/Inverter/VoutL: Q14.1 (C), R13.1, R15.2
/OptoIsolation/Serial_Gnd: C2.2, C3.2, D1.2 (A), D2.2 (A), D3.2 (A), D4.2 (A), D11.1 (K), J1.3, J1.5, J6.4, Q2.1 (C), Q4.1 (C), Q7.3 (E), Q8.3 (E), U2.3
/OptoIsolation/Vcc: C3.1, D6.1 (K), D8.1 (K), D9.1 (K), D10.1 (K), J5.2, J6.3, Q1.1 (C), Q3.1 (C), Q5.3 (E), R5.1, R6.2, R7.2, R8.2
/OptoIsolation/VinL: J3.4, R4.2
/OptoIsolation/VoutL: Q7.1 (C), R2.1, R6.1
/Serial/CD: J2.1, J14.1
/Serial/CTS: J14.7, Q3.3 (E), Q4.3 (E)
/Serial/DTR: D2.1 (K), D9.2 (A), J4.1, J14.4
/Serial/RTS: D3.1 (K), D10.2 (A), J6.1, J14.6
/Serial/RXD: J3.2, J14.2
/Serial/SGND: C2.1, D4.1 (K), D5.2 (A), J1.8, J14.5, R1.2
/Serial/TXD: D1.1 (K), D8.2 (A), J3.3, J14.3
GND: C4.2, C5.1, C6.1, C7.1, C8.1, C9.2, C11.1, C12.1, C13.1, C14.2, D12.1 (K), J7.6 (GND), J8.2, J9.4, J11.2, J12.1, J16.1, J16.2, J16.3, J16.4, Q9.3 (E), Q10.3 (E), Q13.3 (E), Q14.3 (E), Q16.1 (E), R18.2, R24.2, U1.3, U3.8 (GND), U3.22 (GND), U4.1 (GND)
unnamed: C10.2, R23.2
unnamed: C1.1, D5.1 (K), D6.2 (A)
unnamed: D7.2 (A), J5.1
unnamed: D7.1 (K), R1.1
unnamed: D11.2 (A), U1.2
unnamed: D12.2 (A), U2.2
unnamed: D13.2 (A), U3.4 (PD2)
unnamed: D13.1 (K), D14.1 (K), D15.1 (K), R18.1
unnamed: D14.2 (A), U3.5 (PD3)
unnamed: D15.2 (A), U3.6 (PD4)
unnamed: D16.1 (K), R24.1
unnamed: C12.2, D17.2 (A), J7.5 (~RST), R19.2, R20.1, U3.1 (~RESET/PC6)
unnamed: C1.2, J1.2
unnamed: J3.1, Q1.3 (E), Q2.3 (E)
unnamed: J6.2, R3.1
unnamed: J7.1 (MISO), U3.18 (PB4)
unnamed: J7.4 (MOSI), U3.17 (PB3)
unnamed: J7.3 (SCK), U3.19 (PB5)
unnamed: J8.1, R20.2
unnamed: J10.1, U3.14 (PB0)
unnamed: J10.2, U3.15 (PB1)
unnamed: J10.3, U3.16 (PB2)
unnamed: J10.4, U3.9 (XTAL1/PB6)
unnamed: J10.5, U3.10 (XTAL2/PB7)
unnamed: J10.6, U3.23 (PC0)
unnamed: J10.7, U3.24 (PC1)
unnamed: J10.8, U3.25 (PC2)
unnamed: J10.9, U3.26 (PC3)
unnamed: J10.10, U3.13 (PD7)
unnamed: C14.1, J11.1, R25.1
unnamed: C13.2, J11.3, R26.1
unnamed: Q1.2 (B), Q2.2 (B), R2.2
unnamed: Q3.2 (B), Q4.2 (B), R3.2
unnamed: Q5.2 (B), Q6.3 (E), R5.2
unnamed: Q5.1 (C), Q6.2 (B), R4.1
unnamed: Q6.1 (C), U1.1
unnamed: Q7.2 (B), Q8.1 (C), R7.1
unnamed: Q8.2 (B), R8.1, U2.4
unnamed: Q9.2 (B), R9.2, U1.4
unnamed: Q9.1 (C), Q10.2 (B), R11.2
unnamed: Q11.2 (B), Q12.1 (C), R13.2
unnamed: Q11.1 (C), U2.1
unnamed: Q11.3 (E), Q12.2 (B), R12.1
unnamed: Q13.2 (B), R14.2
unnamed: Q14.2 (B), R17.1
unnamed: Q15.2 (B), R21.2
unnamed: Q15.1 (C), R22.2
unnamed: Q16.3 (B), R22.1
unnamed: C8.2, U3.21 (AREF)

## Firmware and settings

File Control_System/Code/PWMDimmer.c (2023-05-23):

// Includes and definitions

#define F_CPU 1000000

#include <avr/io.h>
#include <avr/interrupt.h>
#include <util/delay.h>
#include <string.h>

// Function declaration
int init_LEDs(void);
int set_LED(int position, int value);

int AB=3;
uint8_t duty;

int main(void) {
	
	sei();    // set global interrupt flag -> enable ALL interrupts (but those that are masked won't do anything)
	//set_LED(1,1);
	setup_INTs();
	setup_PWM();
	//set_LED(2,1);
	duty=100;
	update_PWM();
	while(1) {
	
	_delay_ms(200);

		}
	
	return 0;
}

	
int setup_PWM(void) {
	
	DDRD |= ((1<<DDD5)|(1<<DDD6));	//Set PIND5 and PIND6 as outputs
	TCCR0A |= 0b11100011;			//Configure fast PWM mode, non-inverted output on OCB 4 and inverted output on OCA 3 amplifier conected to oca3
	TCCR0B |= 0x01;					//Internal clock selector, no prescaler
	return 1;
}


int setup_INTs(void) {

	PCMSK0 = (1<<PCINT1)|(1<<PCINT2); //PB1 and PB2
	PCICR = (1 << PCIE0);
	return 1;
}


int encoder_read(void) {
    
	//encoder read: function that reads wether the encoder is moving one way or the other: 1 or -1
	int res; //result, 1 or -1 depending on direction
	int An; //Channel A new value fo the encoder
	int Bn; //Channel B new value of the encoder
	int AB_new;
	
	//Read pins and assign values to vbles A2 and B2 (new value after interruption)
	//Chanel A connected to PD2 and chanel B connected to PD3
	An = PINB & (1<<PINB1);
	Bn = PINB & (1<<PINB2);
	
	AB_new=(An|Bn)>>PINB1;
	
	//Make the computations to guess the direction in which the encoder is moving
	switch (AB){
		case 3 : /*AB new up*/  if (AB_new == 2) res=1; /*B moves*/ else  res = 2; break; /* A moves */		
		case 2 : /*A up B down*/if (AB_new == 0) res=1; /*B moves*/ else  res = 2; break; /* A moves */
		case 1 : /*A down B up*/if (AB_new == 3) res=1; /*B moves*/ else  res = 2; break; /* A moves */
		case 0 : /*AB new down*/if (AB_new == 1) res=1; /*B moves*/ else  res = 2; break; /* A moves */
	}
	
	//Set led 1 on if res=1 and led 2 on if res=2, or led 3 on in other case (for debuging)
	
	//Update global variables with new encoder value
	AB = AB_new;
	
	return res;
}

ISR(PCINT0_vect)
{

	cli(); 
	int dir = encoder_read();
	if (dir == 1 && duty < 255 ) {
    duty++;
    }
	else if (dir == 2 && duty > 0) {
    duty--;
    }
	update_PWM();
	sei();
}

int update_PWM(void)
{
	/* Making sure the duty is within the range */
	if (duty < 0) {
         OCR0A = 0;
    }
	else if (duty > 255) {
        OCR0A = 255;
    } else {
        OCR0A = duty;
    }
	return 1;
}

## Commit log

2023-05-23 Added PCB KiCad Project
    [Precision-Lapping-Machine.kicad_pcb, Precision-Lapping-Machine.kicad_sch, amplifier.kicad_sch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]
2023-05-23 Updated Electrical Schematic for PCB in README.md
2023-05-23 Added Code for PWM control with dimmer
2023-05-24 Added Gearbox CAD files
    [Body1.stl, Body13 modified.STL, Body14.stl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]
2023-05-24 Added CAD for arm and self-self aligning weight
    [Assem1.SLDASM, Ball.SLDPRT, SpinningPart.SLDPRT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]
2023-05-24 Added gearbox img
2023-05-24 Revert "Added gearbox img"
    This reverts commit de685fda34cf269d301c6a88953607c8e0699a98.
2023-05-24 Added Gerber files and PCB schematic
    [Precision-Lapping-Machine-5V_Cu.gbr, Precision-Lapping-Machine-B_Cu.gbr, Precision-Lapping-Machine-B_Mask.gbr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]
2023-05-26 Added disc CAD and prototype images
    [Ball.SLDPRT, Bearing_Housing.SLDPRT, Bearing_Housing_P2.SLDPRT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]
2023-05-26 Added gerber plots
2023-05-26 Added PCB CAD img
